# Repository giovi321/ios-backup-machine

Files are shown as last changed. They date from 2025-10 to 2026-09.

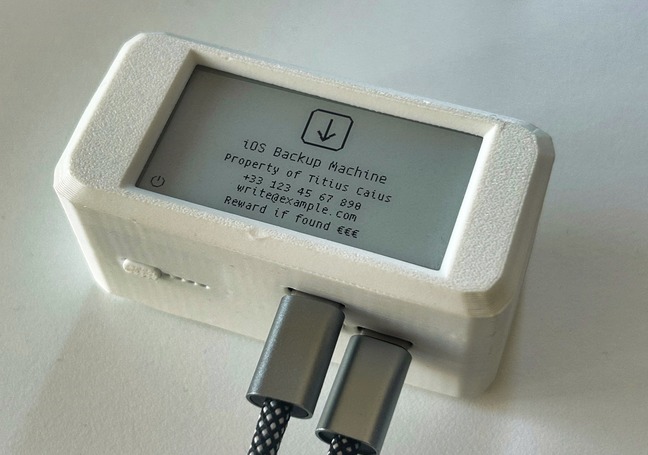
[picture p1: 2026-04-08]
docs/public/assets/images/Image2.jpg

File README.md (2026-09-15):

<p align="center">
  iOS Backup Machine
</p>

<h1 align="center">iOS Backup Machine</h1>

<p align="center">
  
  
  
  
  
</p>

<p align="center">
  
  
  
</p>

<p align="center">
  
</p>

Plug in an iPhone and it backs up on its own. No iCloud, no iTunes, no computer, no account.

The whole appliance runs on a Radxa Zero 3W (an upgraded Raspberry Pi Zero W) with a small e-ink screen and a battery UPS. When you connect a phone, it runs an encrypted `idevicebackup2` backup to the microSD card, shows progress and any errors on the display, and keeps a log you can read later. An optional rsync-over-SSH job ships each backup to a remote server, over WireGuard if you want it off your LAN.

Every backup stays on storage you control, and it can be restored anytime with tools from [libimobiledevice](https://libimobiledevice.org).

Normal operation

> **Personal appliance, not an internet service.** The web UI password is optional and basic, so keep the device on your LAN or reach it over the VPN. The backup payload is encrypted by iOS with a password that never leaves your iPhone.

## Quick start

Flash Armbian on the Radxa Zero 3W, then from the device as root:

```bash
cd /root
git clone https://github.com/giovi321/ios-backup-machine.git
bash ios-backup-machine/install.sh
```

The installer enables the I2C and SPI overlays, installs the packages, builds the Python environment, links the e-Paper driver, installs the systemd services and udev rules, prepares the backup storage, and sets up the PiSugar UPS. When it finishes, open `http://<device-ip>:8080` and complete the first-start wizard.

Full flashing steps, the manual install, and updating are in the [Installation guide](https://giovi321.github.io/ios-backup-machine/getting-started/installation/).

## What it does

- Starts a backup automatically when an iPhone is plugged in, using the iPhone's own encryption
- Shows progress, status, and errors on the e-ink display, with a status icon row for power, VPN, internet, WiFi, and a three-state iPhone icon
- Keeps running on a UPS so a power cut does not corrupt a backup or the filesystem
- Stops a running backup when the backup drive disappears, the drive fills up, or the battery drains, and reports which of the three it was
- Kills a backup that has gone silent, and restarts the daemon if its main loop wedges, so a stuck run does not look like a working one
- Sends one alert when no backup has succeeded for a week, because every other notification only fires when something actually happens
- Ships backups to a remote server over rsync and SSH, with a WireGuard client for off-LAN transfers
- Optionally verifies the sync server's SSH host key against a fingerprint you pin
- Configures everything from a web UI, with a log and journal viewer and a health endpoint for external monitoring
- Encrypts WireGuard, remote sync, and webhook auth credentials at rest with AES-256-GCM

## Documentation

The full documentation is at **[giovi321.github.io/ios-backup-machine](https://giovi321.github.io/ios-backup-machine/)**:

- [Overview](https://giovi321.github.io/ios-backup-machine/getting-started/overview/) and [Hardware](https://giovi321.github.io/ios-backup-machine/getting-started/hardware/)
- [Installation](https://giovi321.github.io/ios-backup-machine/getting-started/installation/) and [First backup](https://giovi321.github.io/ios-backup-machine/getting-started/first-backup/)
- Guides for [backups](https://giovi321.github.io/ios-backup-machine/guide/backups/), [remote sync](https://giovi321.github.io/ios-backup-machine/guide/remote-sync/), [networking](https://giovi321.github.io/ios-backup-machine/guide/networking/), [WireGuard VPN](https://giovi321.github.io/ios-backup-machine/guide/wireguard-vpn/), the [web UI](https://giovi321.github.io/ios-backup-machine/guide/web-ui/), and [logs](https://giovi321.github.io/ios-backup-machine/guide/logs/)
- [Architecture](https://giovi321.github.io/ios-backup-machine/architecture/overview/), including [device connectivity](https://giovi321.github.io/ios-backup-machine/architecture/device-connectivity/) and [security](https://giovi321.github.io/ios-backup-machine/architecture/security/)

## Inspect your backups with Apple Juicer

To browse the backups this device creates, point [Apple Juicer](https://github.com/giovi321/apple-juicer) at the backup directory. It parses artifacts such as WhatsApp and Messages (with Photos, Notes, Calendar, and Contacts in progress), unlocks encrypted backups with the password, and lets you search everything in a browser. Docs: https://giovi321.github.io/apple-juicer/

## Contributing

Issues and pull requests are welcome. See [CONTRIBUTING.md](CONTRIBUTING.md) and the [development docs](https://giovi321.github.io/ios-backup-machine/development/contributing/). Report security issues privately through [Security Advisories](https://github.com/giovi321/ios-backup-machine/security/advisories/new).

## License

MIT License. Includes code adapted from Waveshare's [e-Paper library](https://github.com/waveshareteam/e-Paper).

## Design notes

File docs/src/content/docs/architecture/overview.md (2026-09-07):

---
title: "Architecture overview"
description: One long-running display service owns the e-paper and renders every screen from a single status file, everything else just writes state, and a fault either degrades or restarts the daemon.
---

The design rule is one owner for the e-paper. A single always-on daemon (`iosbackupmachine.service`) holds the display for the whole uptime and draws every screen. Nothing else ever opens the panel. This is what removed the SPI-bus conflicts and the "screen not updating" failures that came from several processes fighting over the same hardware.

Everything else in the system only writes state. The backup logic, remote sync, web UI, and PiSugar button each update a file or drop a small sentinel, and the daemon reads that state and decides what to draw.

System architecture

## The single display owner

The daemon renders all of these from state:

- Boot and idle screen
- Backup progress
- Remote sync progress
- Single-tap system info
- Unplug and interrupted screens
- The power-off owner screen

The rest of the system stays off the panel:

- Backup runs inside the daemon, which detects an iPhone by polling rather than restarting on a udev event. An earlier design restarted the service on plug, which tore down the display owner mid-render.
- Remote sync (`backup-sync.py`) writes progress to the status file, and the daemon draws it.
- The single-tap info screen is handled by the daemon's button listener.
- Unplug is a udev event that only stops a running `idevicebackup2`; the daemon then draws the interrupted screen.
- Shutdown sends the daemon `SIGTERM`, and it paints the owner screen and sleeps the panel so the image survives after power-off.
- The web UI Start and Stop actions drop sentinel files that the daemon consumes, instead of restarting the service.

## State drives the screen

A shared status file is the contract between the writers and the display. The daemon reads it on every tick and paints one full refresh on each screen-type transition, with partial refreshes for animated progress. Because only the daemon touches the panel, there is no lock to contend for and no way for two screens to overlap.

Display state machine

## Failure handling

Because the daemon is the only process that can draw, losing it costs the display for the rest of the uptime. Swallowing every error is the wrong fix, though: a daemon that is alive and doing nothing is the worse failure, since nothing reports it. A fault therefore either degrades to something honest, or exits non-zero so systemd restarts the process.

- Startup faults degrade. An unwritable log directory, a config that crashes the loader, or a panel that will not initialise each cost one capability and leave the rest working, instead of taking the process down.
- Fatal faults exit non-zero, so `Restart=on-failure` on `iosbackupmachine.service` brings a working daemon back rather than leaving a dead one.
- A wedged main loop is caught by a heartbeat watchdog. The loop, and every long hold it can legitimately sit in, beats a timer; if no beat lands inside the window the process logs `[FATAL] main loop stalled` and exits 1.
- Headless is recoverable, not permanent. A daemon running on the no-op panel keeps retrying the real one in the background, so a panel that was busy at boot comes back without a restart. See [Display and controls](../../guide/display-and-controls/#when-the-panel-does-not-come-up).
- A backup is guarded during the run, not only before it. One health probe re-checks the drive, the free space, and the battery every 10 seconds, and a silence timeout and a total cap bound a run that is producing nothing. See [Backups](../../guide/backups/#guards-during-a-backup).
- A `config.yaml` that cannot be read falls back to the built-in defaults instead of failing to start, keeps the bad file for inspection, and says so in the web UI. See [Security](../security/#config-integrity).

Every guard fails open in the direction that keeps the appliance usable: a probe that cannot answer lets the work through, because a guard misfiring on its own broken probe is worse than the failure it was added to prevent. The quiet-device alert is the one inversion, and for the mirror-image reason. It fails silent, because one false alarm there costs the credibility of every later true one.

## Where to go next

- [Device connectivity](../device-connectivity/): how the daemon keeps an iPhone visible and the VPN handshaking
- [Security](../security/): credential encryption, web UI auth, and what the appliance trusts
- [Display and controls](../../guide/display-and-controls/): the screens and the button actions from a user's point of view

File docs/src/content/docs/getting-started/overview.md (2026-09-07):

---
title: "Overview"
description: What the iOS Backup Machine appliance is, its key features, and how a normal backup runs.
---

iOS Backup Machine is an offline, portable, automatic iPhone backup appliance that runs entirely on a Radxa Zero 3W (an upgraded Raspberry Pi Zero W). Plug in an iPhone and the device runs an encrypted `idevicebackup2` backup to local storage, shows progress and messages on a 2.13" e-ink display, and logs all activity locally. No iCloud, no iTunes, you own your data.

Normal operation

## Objective

A self-contained iOS backup appliance with no reliance on Apple services or computers. All backups stay local on the microSD card and can be restored anytime using tools from [libimobiledevice](https://libimobiledevice.org).

## Key features

- Fully automated: starts as soon as an iPhone is plugged in
- Live feedback: the e-ink display shows progress, status, and errors
- Secure: backups use the iPhone's own encryption credentials
- Offline and independent: no Apple ID, no iTunes, no internet required
- Solid: file corruption is prevented by a small UPS
- Guarded runs: a backup is stopped and the reason reported when the backup drive disappears, the drive fills up, the battery drains, or the run hangs
- Quiet-device alert: one notification when no backup has succeeded for a week, since every other notification only fires when something happens
- Web UI: configure all settings from a browser, with a bounded log viewer and a systemd journal viewer for diagnosing a bad run
- Status icons: every e-ink screen shows power, VPN, internet, WiFi, and iPhone indicators at a glance, with a three-state iPhone icon (absent, plugged but untrusted, trusted)
- Multi-network WiFi: configure several networks (each with a nickname); the device roams to whichever is in range, managed through netplan and wpa_supplicant
- NTP sync: auto-syncs the clock when internet is available (WiFi or USB iPhone hotspot)
- Notifications: webhook and MQTT alerts for backup events
- Remote sync: rsync backups to a remote server over SSH (manual or auto after a backup)
- WireGuard VPN: built-in client with encrypted config, auto-connect on boot, WiFi, or iPhone, and an optional full-tunnel mode that keeps local SSH and web UI access
- Credential encryption: WireGuard, remote sync, and webhook auth credentials are encrypted with AES-256-GCM, using either the iPhone UDID (auto-decrypt when connected) or a custom password
- Network-aware sync: restrict remote sync to WiFi only, a specific SSID, or iPhone USB tethering

## How normal operation works

1. Turn on the device: press the PiSugar power button once, then keep it pressed until all LEDs light up
2. Wait for the boot to complete (you will see a screen refresh)
3. Plug in your iPhone and the backup starts automatically
4. Follow the display, which prompts to unlock the phone if needed, shows encryption status, and shows the progress percentage
5. At the end, the display shows a success confirmation and timestamp, plus owner info that persists on screen even after power off or power loss

:::note
If you unplug the iPhone during a backup, the process stops safely and the screen shows the interruption timestamp. Encryption stays active on the iPhone, so the next attempt continues normally.
:::

## Next steps

- [Installation](../installation/)
- [First backup](../first-backup/)
- [Architecture overview](../../architecture/overview/)

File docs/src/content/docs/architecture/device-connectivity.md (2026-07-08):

---
title: "Device connectivity"
description: How the daemon keeps a hot-plugged iPhone visible to usbmux and verifies the VPN actually handshakes.
---

The daemon works around two platform quirks so that plugging in an iPhone "just works" regardless of order or lock state: a usbmux hot-plug gap that hides devices connected after boot, and a VPN that can look up without ever handshaking. Both are handled inside the always-on display daemon, so there is no dependency on udev delivering an event at the right moment.

## The usbmux hot-plug gap

On this Armbian image, `usbmuxd` runs as a persistent service but does not receive libusb hot-plug events. A phone plugged in after boot is enumerated by the kernel (it shows up in `lsusb` as an Apple device, vendor `05ac`) but stays invisible to `idevice_id` and every other `libimobiledevice` tool until `usbmuxd` re-scans. Since the daemon detects an iPhone by polling `idevice_id`, an invisible device blocks backup detection, the trust icon, and the VPN's config decryption at the same time.

The daemon closes the gap itself. On each idle poll, if it finds no device through `idevice_id` but the kernel has enumerated an Apple device in sysfs (`/sys/bus/usb/devices/*/idVendor` reads `05ac`), it restarts `usbmuxd` so the device appears.

The restart is guarded so it never misfires or storms:

- It never runs during a backup, which would drop the `idevicebackup2` usbmux session
- It tracks a sysfs signature of the device (bus path, `devnum`, interface and configuration counts). A fresh plug, or a re-enumeration when you unlock a phone, changes the signature and triggers a restart at once
- A device that stays invisible is retried with exponential backoff (8 seconds up to 120 seconds), so unlocking it later is picked up quickly, and a phone left plugged in and locked does not restart `usbmuxd` on a tight loop

Once `usbmuxd` sees the phone, the backup path and the VPN reconciler both proceed on their next cycle.

:::note[iOS USB Restricted Mode]
A phone that has been locked for about an hour puts its USB data port into Restricted Mode: it charges but exposes no data, so no software on this side can reach it. Unlock the phone once and the daemon picks it up within a few seconds. This is an iOS security feature, not something the appliance can bypass.
:::

## Three trust states

The iPhone status icon reflects what the daemon can actually read, which is what the rest of the system depends on:

- Absent: no iPhone is visible on USB
- Untrusted (closed padlock): the phone is plugged in but lockdown data is not readable yet, either because Trust has not been granted or the phone is locked
- Trusted (checkmark): lockdown data (the serial number) is readable

The trusted state matters beyond the icon. In `udid` decryption mode the WireGuard config is decrypted with the iPhone serial, so the tunnel can only come up once the phone is readable. See [WireGuard VPN](../../guide/wireguard-vpn/) and [Security](../security/).

## Handshake-verified VPN

The VPN reconciler treats a real WireGuard handshake as the definition of "connected", not the mere existence of the `wg0` interface. A tunnel can come up and then never handshake, for example when the endpoint is unreachable or the clock is not yet NTP-synced and the peer rejects the exchange.

The reconciler runs in the display daemon and does two things:

- Brings the tunnel up as soon as a selected auto-connect source appears (iPhone plugged in, WiFi available, or on boot), so it recovers after errors, reconnects, or a hotspot toggled on after the phone was already plugged in, not just on a one-off boot event
- Checks that a handshake completes within a grace window. If the interface is up but no handshake lands, it tears the tunnel down and reconnects

In `udid` mode the reconciler waits for a readable iPhone before it can decrypt the config, and the persisted WireGuard log records `Cannot decrypt: no iPhone connected` while it waits.

For the user-facing view of triggers and the full-tunnel option, see [WireGuard VPN](../../guide/wireguard-vpn/). For the icons, see [Display and controls](../../guide/display-and-controls/).

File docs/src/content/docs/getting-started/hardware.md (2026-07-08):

---
title: "Hardware"
description: The bill of materials and the software stack that make up the iOS Backup Machine appliance.
---

The appliance is built from four hardware parts (a Radxa Zero 3W, a Waveshare e-ink HAT, a PiSugar 3 UPS, and a microSD card) inside a 3D printed case, running an Armbian and Python software stack. This page lists each part and its role.

## Bill of materials

| Component | Purpose | Rationale |
|---|---|---|
| Radxa Zero 3W (8GB eMMC) | Main controller | eMMC is faster and more reliable than a microSD |
| Waveshare 2.13" e-Paper HAT V4 (250x122) | Status display | Persistent output, readable, low power |
| PiSugar 3 | UPS and safe shutdown | Prevents corruption on power loss |
| MicroSD card | Backup storage | Dedicated storage separate from the OS |
| 3D printed case | Enclosure | Based on the design by PiSugar and edited for this purpose |

:::note
The 3D printed case is based on the PiSugar case design, edited to fit this build.
:::

## Software stack

| Component | Role |
|---|---|
| Armbian (Trixie) | Base OS |
| Python 3.13 | Runtime for backup and display scripts |
| libimobiledevice | iPhone communication (`idevicebackup2`, `idevicepair`) |
| udev and systemd | Automation and event handling |
| netplan, systemd-networkd, wpa_supplicant | WiFi management (no NetworkManager) |
| Flask | Web UI for settings |
| WireGuard | Optional VPN client (auto-connect, optional full tunnel) |

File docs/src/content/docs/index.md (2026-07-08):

---
title: "iOS Backup Machine"
description: Offline, automatic iPhone backup appliance on a Radxa Zero 3W, with an e-ink display, a UPS, and encrypted remote sync.
---

<div style="text-align: center; margin-bottom: 1rem;">
  iOS Backup Machine
</div>

Plug in an iPhone and it backs up on its own. No iCloud, no iTunes, no computer, no account. The whole thing runs on a Radxa Zero 3W (an upgraded Raspberry Pi Zero W) with a small e-ink screen and a battery UPS, and every backup stays on local storage you control.

When you connect a phone, the device runs an encrypted `idevicebackup2` backup to the microSD card, shows progress and any errors on the e-ink display, and writes a log you can read later. An optional rsync-over-SSH job ships each backup to a remote server, over WireGuard if you want it off your LAN.

Normal operation

:::caution[Built for a trusted network]
This is a personal appliance, not a hardened internet service. The web UI password is optional and basic, so keep the device on your LAN or reach it over the VPN. The backup payload is encrypted by iOS with a password that never leaves your iPhone.
:::

## Start here

- [Overview](getting-started/overview/): what the appliance does and how a backup runs
- [Hardware](getting-started/hardware/): the parts list and the software stack
- [Installation](getting-started/installation/): flash Armbian and run the installer
- [First backup](getting-started/first-backup/): the setup wizard and your first run

## How it fits together

One long-running display service owns the e-paper and draws every screen from a single status file. Everything else (the backup, remote sync, web UI, and the PiSugar button) only writes state. Backups land on the microSD card, and an optional rsync-over-SSH job copies them to a remote server.

System architecture

Read [Architecture overview](architecture/overview/) for why a single owner removes the SPI-bus conflicts that used to freeze the display.

## Inspect your backups with Apple Juicer

To browse the backups this device creates, point [Apple Juicer](https://github.com/giovi321/apple-juicer) at the backup directory. It parses artifacts such as WhatsApp and Messages (with Photos, Notes, Calendar, and Contacts in progress) and lets you search them in a browser, including unlocking encrypted backups with the password.

- Repository: https://github.com/giovi321/apple-juicer
- Documentation: https://giovi321.github.io/apple-juicer/

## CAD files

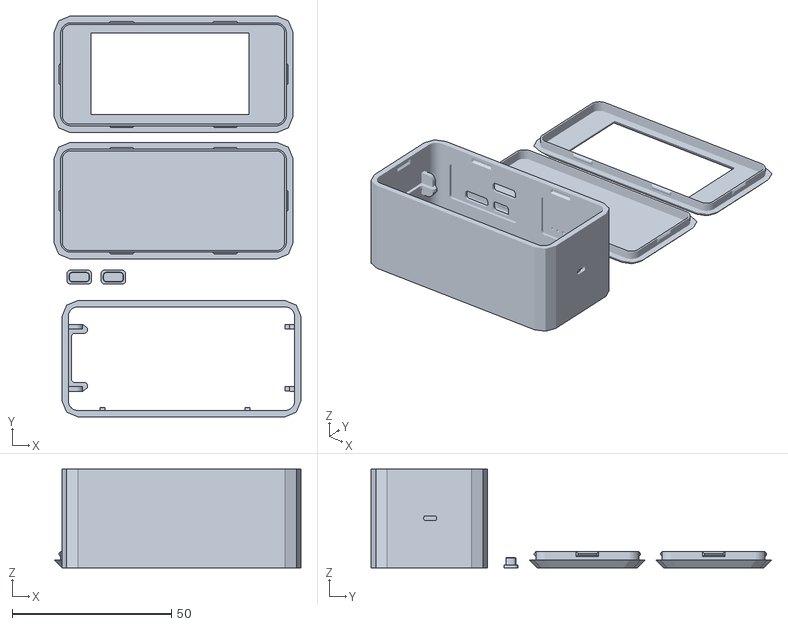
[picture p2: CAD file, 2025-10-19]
assets/case/Case ios backup machine_v8.stl
77.5 x 125.7 x 31.0

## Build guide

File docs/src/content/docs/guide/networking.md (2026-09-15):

---
title: "Networking"
description: How the appliance manages WiFi, roams between saved networks, prefers the iPhone hotspot, and keeps its clock in sync.
---

This page covers how the iOS Backup Machine connects to a network. WiFi is handled by the OS stack (netplan, systemd-networkd, wpa_supplicant), the device roams between the networks you save, and it prefers the iPhone USB hotspot while the phone is plugged in. Network access is optional: backups run fully offline, but a connection enables NTP sync, notifications, remote sync, and remote access.

## WiFi stack

WiFi is managed through the OS's existing netplan, systemd-networkd, and wpa_supplicant stack. The device has no NetworkManager. The `iw` and `wireless-tools` packages read the connected SSID, and `iptables` is used by the WireGuard full-tunnel routing exception.

When you save networks in the web UI, the appliance writes a managed netplan drop-in at `/etc/netplan/90-iosbackup-wifi.yaml` and applies it. The OS's own netplan files are left untouched.

:::note
Only the `90-iosbackup-wifi.yaml` drop-in is owned by the appliance. Your base OS network configuration is never rewritten.
:::

## Multiple networks and roaming

You can configure several networks, each with an optional nickname. wpa_supplicant associates to whichever configured network is in range, so the device roams automatically as you move between them.

Networks are stored in `config.yaml` under `wifi.networks`:

```yaml
wifi:
  enabled: false
  ssid: ""
  password: ""
  networks:
    - nickname: "Home"
      ssid: "HomeNetwork"
      password: "secret"
    - nickname: "Office"
      ssid: "CorpWiFi"
      password: "another-secret"
```

The legacy single `ssid` and `password` fields are the older single-network form. They are migrated into `networks[0]` automatically and kept mirrored for back-compat, so an existing single-network config keeps working.

## iPhone-hotspot preference

The WiFi route is given a higher metric than the iPhone USB tether's route. As a result, the iPhone hotspot is used when the phone is plugged in, and WiFi takes over automatically when the phone is unplugged. The WiFi connection is no longer dropped as the iPhone connects or disconnects.

This handover changes which addresses the device answers on, which matters if you have restricted `webui.bind_interfaces` to specific interfaces rather than `all`. The web UI re-checks the selection every 20 seconds and binds and unbinds as addresses appear and disappear, so a handover mid-sync does not strand it. See [Web UI](../web-ui/#access).

## Scan and connect

The WiFi settings page has a Scan & connect button. It forces a rescan and connects to any saved network in range. Use it when the device is not associated to a network you expect to be reachable.

## Status sources

The connected SSID and its nickname are shown in three places: the dashboard, the e-ink info screen (single-tap system info), and `GET /api/status`. These values are read via `iw`, `iwgetid`, and `wpa_cli`.

The `/api/health` and `/api/status` responses expose the active interface and WiFi details, for example:

```json
"network": {
  "active_ip": "192.168.1.50",
  "interface": "wifi",
  "wifi_ssid": "HomeNetwork",
  "wifi_nickname": "Home",
  "internet": true
}
```

## NTP time sync

When `ntp.enabled` is true, the appliance auto-syncs its clock whenever internet is available, over either WiFi or the USB iPhone hotspot. A correct clock matters beyond timestamps: the WireGuard peer rejects handshakes when the clock is not yet NTP-synced.

```yaml
ntp:
  enabled: true
  servers:
    - "pool.ntp.org"
    - "time.google.com"
```

`ntp-sync.service` runs once at boot, which can easily land before any network is up. `ntp-sync.timer` covers that: it first fires two minutes into the boot and then retries every 15 minutes. The retry is cheap in the steady state, because `ntp-sync.py` exits early once `timedatectl` reports `NTPSynchronized=yes`. The installer both enables and starts the timer, so a fresh or changed timer does not wait for the next boot to begin running.

The clock also gates the quiet-device alert. A board with a dead RTC cell and no network boots reading 1970, so the alert refuses to write its first record until the clock reads at least 2026, and it ignores the first 15 minutes of a boot entirely. Anchoring the record to a 1970 clock would make the next check compute an age of decades and alert on a healthy device.

## Related

- [WireGuard VPN](../wireguard-vpn/) covers the VPN client and its WiFi and boot auto-connect triggers
- [Remote sync](../remote-sync/) covers restricting rsync to WiFi only, a specific SSID, or iPhone USB tethering

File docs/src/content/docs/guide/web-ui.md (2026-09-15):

---
title: "Web UI"
description: The browser interface at port 8080, its first-start wizard, live dashboard, settings pages, authentication, and the login-exempt health endpoint.
---

The web UI is where you configure the appliance and watch it work. Open it at `http://<device-ip>:8080`. On the very first boot it runs a nine-step setup wizard, then it settles into a dashboard with three live cards and a set of settings pages. A login-exempt `GET /api/health` endpoint exposes a JSON snapshot for external monitoring.

## Access

Access the web interface at `http://<device-ip>:8080`. The port is configurable in `config.yaml` under `webui.port`, and `webui.bind_interfaces` selects which network interfaces the UI listens on (options: `all`, `wifi`, `usb_iphone`, `wireguard`). Select several and the UI listens on each one that has an address. The selection is re-checked every 20 seconds, so an interface that comes up later, a WireGuard tunnel or the iPhone hotspot, starts being served without a restart, and one that goes away stops being served. If none of the selected interfaces has an address the UI listens on nothing and records that in the journal, rather than falling back to every interface.

## First-start wizard

On the very first boot, when owner info has not been configured, the web UI shows a guided setup wizard. It opens with an unnumbered step asking you to plug the iPhone in and pair it, then nine numbered ones:

1. Owner information, displayed on the e-ink screen when idle
2. WiFi (optional), for NTP sync, notifications, and remote access
3. Date & time, set manually or with automatic NTP synchronization
4. Backup directory, where backups are stored
5. Backup encryption, set directly on the iPhone (the password is never stored on this device)
6. Device filter (optional), restrict which iPhones can trigger a backup, auto-detects the connected device
7. Notifications (optional), webhook and MQTT alerts for backup events
8. Display orientation, landscape left or right
9. Web UI password (optional), protect the settings interface

The Flask session `secret_key` is generated automatically on first start and saved to `config.yaml`. No manual configuration is needed.

## Dashboard

The dashboard shows three live status cards, each refreshing every 5 seconds, above static System, Storage, and Quick Actions cards and the Reboot / Shut Down buttons:

- Network, showing whether the internet is reachable, which link is carrying it (WiFi with its nickname, or the iPhone's USB hotspot), whether WireGuard is up, and how long the current state has held. The appliance switches links on its own, so how long the current one has lasted sits next to whether it is up. The probe runs on its own schedule and the page reads a cached answer, so polling costs nothing no matter how many tabs are open
- Backup Status, with inline Start Backup and Stop Backup buttons. It shows percentage and encryption status while a backup is running, and stays idle while a remote sync is in progress
- Remote Sync Status, with inline Sync Now (or Cancel Sync, when active) and a Configure shortcut when sync is disabled. It shows percent, transferred and total size, current speed, an ETA, and stall or scanning hints

See [Backups](../backups/) and [Remote sync](../remote-sync/) for what these cards drive.

## Reboot, shutdown, and update while work is running

Reboot, shutdown, and a system update are the three actions that end work in flight. The first two cut the power out from under `idevicebackup2`. The updater stops every service, and the display daemon's `KillMode=mixed` reaps the `idevicebackup2` child along with it. A backup killed that way leaves a half-copied snapshot the next run has to redo, and no `[INTERRUPT]` line in the run log to say why.

All three refuse once while a backup or a sync is running, and offer a button to do it anyway. Taking the override stops the work the sanctioned way first: it drops the stop sentinel the daemon watches and waits up to 10 seconds for `idevicebackup2` to exit, so the run log records why it ended, then it continues.

The refusal is never a hard block. The offer rides on the `?confirm=` query argument of the page you land on, so it disappears as soon as you navigate anywhere else and there is no server-side state to expire or leak between browsers. The busy check itself fails open, because a wedged `pgrep` must not be able to lock you out of powering the device off.

## Pages

The sidebar groups the pages under Backup, Settings, and Tools.

Backup:

- Backup Settings: auto-start toggle, notification on rejected devices. The backup guards and timeouts are config-file only; see [Backups](../backups/#where-these-settings-live)
- Backup List: one row per backup folder on the drive, with the device name, its iOS version, the last backup time, the size (measured in the background), whether the backup completed, and its remote-sync state
- Device Filter: allow only specific iPhones by UDID (auto-detect connected device or manual entry)
- Encryption: enable or change backup encryption on the connected iPhone (password never stored)

Settings:

- General: backup directory, display orientation, owner information, and config export and import
- Date & Time: manual date setting, NTP sync configuration
- WiFi: enable or disable and configure one or more networks, each with an optional nickname, plus a Scan & connect button
- Notifications: webhook URLs and MQTT broker settings (separate test buttons for webhook, MQTT, and both)
- Remote Sync: enable, configure SSH credentials (encrypted), test connection, trigger sync, set network restrictions, and the overall time limit
- WireGuard: upload and encrypt VPN config, start or stop the interface, auto-connect triggers, and a full-tunnel toggle
- Web UI: select which network interfaces the web UI listens on, one or several
- Password: protect the web UI with a password (set, change, or remove)

Tools:

- Logs: browse the log files, with separate live-tail links for the most recent backup and sync log, and a viewer for the systemd journal. See [Logs](../logs/)
- Update: check for a new release and install it, with the output following in `iosbackup-update`. See [Installation](../../getting-started/installation/#updating)

## Authentication

By default the web UI has no password. You can set one during the first-start wizard or later on the Password page. Once set, all pages require login. The password is hashed (SHA-256 plus salt) and stored in `config.yaml`. You can change or remove it at any time.

```yaml
auth:
  password_hash: ""   # auto-managed; set via web UI
```

## Config export and import

The General page exports `config.yaml` as a download and imports one back. An import is migrated and default-filled before it is saved, so a file exported from an older release comes back on the current schema.

The import also reports what it had to correct. A wrong-typed value is silently swapped for its default during the merge, and the corrected tree is what gets saved, so without the report you would never learn which of your settings the import dropped. The first 10 corrections appear as banners and the full list goes to `webui.log`.

Uploads are capped at 256 KB. This import is the only upload in the UI and an exported config is a few KB, so the cap is there for the case where the wrong file gets picked in the browser. Without it, a photo or a backup archive would be read whole into RAM and handed to the YAML parser on a board with 512 MB of it.

## When config.yaml is unreadable

A `config.yaml` that cannot be parsed, or that parses to something other than a settings mapping, does not stop the appliance. The loader falls back to the built-in defaults, keeps the original next to it as `config.yaml.bad-<timestamp>`, and the web UI shows a banner saying so, with the specific problems under Details. The saved settings are gone in that case, including the flag that records setup as finished and the password hash, so the first-start wizard re-engages as the recovery path rather than leaving an open UI that pretends setup was done.

A single mistyped key is handled more narrowly: that value is replaced with its default, a warning is recorded, and the rest of the file is kept.

## Health endpoint

`GET /api/health` returns a JSON snapshot for external monitoring such as Uptime Kuma, Home Assistant, or a cron check. It is login-exempt and contains no secrets: no owner info, credentials, or keys.

```json
{
  "status": "ok",
  "warnings": [],
  "version": "4.10.0",
  "time": "2026-05-30T11:13:31",
  "services": { "iosbackupmachine": "active", "webui": "active",
                "pisugar-server": "active", "usbmuxd": "active" },
  "disk":     { "root": {}, "backup": { "free": "...", "percent": 42.0 } },
  "battery":  { "percent": 62.0, "charging": false },
  "network":  { "active_ip": "192.168.1.50", "interface": "wifi",
                "wifi_ssid": "HomeNetwork", "wifi_nickname": "Home",
                "internet": true, "wireguard": {} },
  "backup":   { "state": "complete", "last_backup_time": "..." },
  "sync":     { "state": "sync_complete", "timestamp": "..." }
}
```

The `status` field is a rollup, and `warnings` names each condition that contributed:

- `error`: `iosbackupmachine.service` or `webui.service` failed, or the backup disk is at 95 percent or more
- `warning`: battery below `sync.min_battery_percent` while not charging, no internet, the last backup errored, or no backup has succeeded for `backup.stale_after_sec` (reported as `no backup in N days`)
- `ok`: none of the above

The stale warning is the pull half of the quiet-device alert described in [Backups](../backups/#the-quiet-device-alert). A poller reading this endpoint catches both a device that is up but quiet and a device that has stopped answering, and the second of those is something the device can never report about itself.

:::note
`GET /api/health` is the only endpoint exempt from login, so external monitors can poll it even when a web UI password is set.
:::

## Notifications

Backup and sync events can be sent via webhook (JSON POST) and MQTT. Supported events: `backup_start`, `backup_complete`, `backup_error`, `backup_stale`, `sync_start`, `sync_complete`, `sync_error`, `device_connected`, `device_disconnected`, `device_rejected`. Configure them on the Notifications page or directly in `config.yaml`. An empty event list means every event.

A `backup_error` carries its own `reason_code` drawn from the backup guards and timeouts; see [Backups](../backups/#notifications).

### The `sync_error` payload

A failed sync sends the same verdict its log records, structured so an automation can act on it without matching English:

```json
{
  "event": "sync_error",
  "timestamp": "2026-05-14T22:15:14+0200",
  "source": "iosbackupmachine",
  "error": "Sync failed at 40% (20.0 GB of 50.0 GB) after 1h10m: SSH/connection error (host unreachable, auth, or link dropped) [exit 255]",
  "reason_code": "ssh_connection_failed",
  "summary": "SSH/connection error (host unreachable, auth, or link dropped)",
  "exit_code": 255,
  "percent": 40,
  "bytes_transferred": 21474836480,
  "bytes_total": 53687091200,
  "duration_seconds": 4200,
  "last_file": "00008030-.../Snapshot/9c/9c11ab04",
  "diagnostics": [
    "no OOM kill of rsync in recent dmesg",
    "remote 192.168.1.50:22 unreachable ([Errno 110] Connection timed out)",
    "wg0 last handshake 12m ago"
  ]
}
```

`reason_code` is the field to branch on. It is stable: codes are added, never renamed. The current set:

| Group | Codes |
|---|---|
| Never started | `sync_disabled`, `config_incomplete`, `credentials_unavailable`, `host_key_mismatch`, `network_not_allowed`, `battery_low`, `tool_missing` |
| Aborted by a watchdog | `scan_timeout`, `stall_timeout`, `battery_abort`, `run_timeout` |
| rsync exited non-zero | `ssh_connection_failed`, `rsync_protocol_error`, `socket_io_error`, `file_io_error`, `source_selection_error`, `partial_transfer`, `remote_timeout`, `out_of_memory`, `rsync_usage_error`, `killed_by_signal`, `no_exit_status`, `rsync_error` |
| Anything else | `internal_error` |

`error` repeats `message` so an existing consumer reading `error` keeps working. Fields the failure does not know are `null`: a sync that never started reports no percentage rather than a misleading `0`.

### Delivery

Webhook and MQTT deliveries run on background threads so a slow endpoint never holds up a backup or a sync. Short-lived callers wait for them before exiting, via `notifications.flush()`; that call is also registered with `atexit`, so a delivery cannot be cut short by the process ending.

Delivery is best-effort and is not retried. A notification reporting a network failure has to travel over the network that just failed, so a `sync_error` caused by a dead link may not arrive. The sync log on the device is the authoritative record; see [Logs](../logs/).

### Webhook auth and the iPhone

The optional webhook auth header is encrypted with the iPhone's serial number, so decrypting it needs the phone attached. Most events that carry it do not fire while it is: `device_disconnected` by definition, every `sync_*` after the phone was unplugged, and `backup_complete`, which is sent just after the screen has invited you to unplug.

The resolved header is therefore cached in `/run/iosbackupmachine/webhook_auth.json`, owner-only, and reused when the phone is absent. `/run` is a systemd tmpfs: RAM-only, cleared at every boot and never written to the SD card, so a powered-off device still gives nothing away without the phone. Only the derived header is cached, never the passphrase - the passphrase also unlocks the WireGuard and remote-sync credentials.

The cache is refreshed whenever the phone is seen, primed at the start of every backup, and dropped when notification settings are saved. Set `IOSBACKUP_WEBHOOK_AUTH_TTL` to a number of seconds to expire it sooner; the default of `0` means it lasts until the next reboot.

If auth is enabled and no header can be obtained, the webhook is skipped rather than sent unauthenticated, and the reason is written to the run's log.

## Related

- [Backups](../backups/) for the backup flow the dashboard controls
- [Remote sync](../remote-sync/) for the sync card and its network restrictions
- [Security](../../architecture/security/) for password hashing and credential encryption

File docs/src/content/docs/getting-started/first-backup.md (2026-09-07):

---
title: "First backup"
description: Complete the first-start wizard, set backup encryption on the iPhone, run the first backup, and restore when needed.
---

After installation, open the web UI at `http://<device-ip>:8080` and complete the first-start wizard, then set backup encryption on the iPhone and run the first backup. The first backup is a full, slow run; every later backup is incremental and much faster.

## First-start wizard

On the very first boot (when owner info has not been configured), the web UI automatically shows a guided setup wizard. It also re-engages if `config.yaml` ever has to be discarded, since the saved setup state goes with it.

The wizard opens with an unnumbered step: plug the iPhone in over USB, click Pair Device, and tap Trust on the phone. Do that before finishing setup, because two later steps (encryption and the device filter) need a readable phone. Then it walks through nine steps:

1. Owner information, displayed on the e-ink screen when idle
2. WiFi (optional), to connect to a wireless network for NTP sync, notifications, and remote access
3. Date and time, set manually or with automatic NTP synchronization
4. Backup directory, where backups are stored
5. Backup encryption, set directly on your iPhone (the password is never stored on this device)
6. Device filter (optional), to restrict which iPhones can trigger a backup; it auto-detects the connected device
7. Notifications (optional), webhook and MQTT alerts for backup events
8. Display orientation, landscape left or right
9. Web UI password (optional), to protect the settings interface

The Flask session `secret_key` is generated automatically on first start and saved to `config.yaml`, so no manual configuration is needed.

## Backup encryption

Set backup encryption during the wizard, or later from the Encryption page in the sidebar. Enter a password with your iPhone connected and unlocked. The password is sent directly to the iPhone.

:::caution
The encryption password is never stored on this device. Write it down. Without it you cannot restore an encrypted backup.
:::

If no iPhone is connected during setup, skip the encryption step and visit the Encryption page later when your iPhone is plugged in.

## Run the first backup

1. Plug in your iPhone, unlock it, and tap Trust when prompted
2. The first backup runs; this takes a long time depending on device storage
3. All subsequent backups are incremental and much faster

If the first backup is interrupted, encryption (if enabled) remains active on the iPhone. The next backup attempt proceeds normally and no data is lost.

## Restoring a backup

To restore a backup, plug your iOS device into a computer, plug the microSD card into the same computer, and run:

```bash
idevicebackup2 restore --password <your backup password> /media/sdcard/iosbackup/
```

## Related pages

- [Backups](../../guide/backups/)
- [Web UI](../../guide/web-ui/)

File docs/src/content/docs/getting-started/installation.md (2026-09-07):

---
title: "Installation"
description: Flash Armbian, run the automated installer, complete setup in the web UI, and keep the appliance updated.
---

Install the appliance in three moves: flash Armbian on the Radxa Zero 3W, run the automated installer over SSH, then finish setup in the web UI at `http://<device-ip>:8080`. A manual, step-by-step reference is included at the end for anyone who prefers to install by hand.

## Flash Armbian on the Radxa Zero 3W

Follow the [Radxa Zero 3W official guide](https://docs.radxa.com/en/zero/zero3/low-level-dev/install-os-on-emmc). In short:

```bash
apt install rkdeveloptool
rkdeveloptool db rk356x_spl_loader_ddr1056_v1.12.109_no_check_todly.bin
xz -d Armbian_community_25.11.0-trunk.334_Radxa-zero3_trixie_vendor_6.1.115_minimal.img.xz
rkdeveloptool wl 0 Armbian_community_25.11.0-trunk.334_Radxa-zero3_trixie_vendor_6.1.115_minimal.img
rkdeveloptool rd
```

## Automated install (recommended)

After flashing Armbian and logging in as root, clone the repository and run the installer:

```bash
cd /root
git clone https://github.com/giovi321/ios-backup-machine.git
bash ios-backup-machine/install.sh
```

The repository is cloned to `/root/ios-backup-machine/` and the application is installed to `/root/iosbackupmachine/` (a flat directory holding the venv and app files).

### What the installer does

- Enables I2C and SPI overlays in `/boot/armbianEnv.txt`
- Installs system packages (`libimobiledevice`, `python3`, `wireguard-tools`, and others)
- Creates a Python virtual environment and installs dependencies
- Clones and links the Waveshare e-Paper driver
- Copies application files to `/root/iosbackupmachine/`
- Migrates config, merging new defaults without overwriting existing settings, and reports which keys it added
- Installs the systemd units and udev rules, enables the six units the appliance needs, and starts any enabled timer instead of leaving it armed for the next boot
- Prepares the backup storage directory
- Downloads and configures the PiSugar UPS
- Runs a post-install health check
- Prompts to reboot when overlay changes were made or a release sets a reboot flag, so the always-on display daemon reloads

## Complete setup in the web UI

After the script finishes, open the web UI at `http://<device-ip>:8080` to complete the first-start wizard. See [First backup](../first-backup/) for the wizard steps and the first backup run.

## Updating

From the web UI: go to Tools > Update, click "Check for Updates", then "Install Update". The device reboots when the update finishes, so the web UI and the VPN are unreachable for about a minute. The e-ink shows `Updating - device will reboot` for the whole run.

From SSH:

```bash
bash /root/ios-backup-machine/update.sh
```

The update process:

- Stops all services before touching files
- Backs up the current installation, keeping the last 5 backups in `/root/iosbackupmachine-backups/`
- Pulls the latest code from GitHub
- Migrates config, adding new settings without overwriting your values
- Runs the installer with a post-install health check
- Restarts services, then reboots: always for a web UI update, and after a prompt over SSH when the release requires one

An update started from the web UI runs in its own systemd unit (`iosbackup-update`), not as a child of the web UI, so restarting the web UI partway through the install cannot cut it short. Follow it with `journalctl -u iosbackup-update -f`, or read `/var/lib/iosbackupmachine/update.log` afterwards.

<details>
<summary>Manual installation (step-by-step reference)</summary>

If you prefer to install manually, follow these steps after flashing Armbian.

#### Enable I2C and SPI

Edit `/boot/armbianEnv.txt`:

```text
overlays=rk3568-spi3-m1-cs0-spidev rk3568-i2c3-m0
overlay_prefix=rk35xx
```

Reboot.

#### Install dependencies

```bash
apt update
apt install -y python3 python3-venv python3-pil python3-periphery \
  libimobiledevice-1.0-6 libimobiledevice-utils usbmuxd \
  wireguard-tools iptables sshpass rsync netcat-traditional \
  iw wireless-tools git
```

WiFi is managed through the OS's existing netplan, systemd-networkd, and wpa_supplicant stack (the device has no NetworkManager). `iw` and `wireless-tools` read the connected SSID, and `iptables` is used by the WireGuard full-tunnel routing exception.

#### Create the Python virtual environment

```bash
python3 -m venv /root/iosbackupmachine
source /root/iosbackupmachine/bin/activate
pip install -r /root/ios-backup-machine/requirements.txt
deactivate
```

#### Clone repositories and install drivers

```bash
cd /root
git clone https://github.com/waveshareteam/e-Paper.git
git clone https://github.com/giovi321/ios-backup-machine.git
cp ios-backup-machine/app/epdconfig.py e-Paper/RaspberryPi_JetsonNano/python/lib/waveshare_epd/
```

The application files live under `app/`, the systemd units under `services/`, and the udev rules and the PiSugar config under `config/`. The installer flattens `app/` into `/root/iosbackupmachine/`, which is why the modules import each other by bare name.

Link the driver into the venv (adjust the Python version if needed):

```bash
ln -s /root/e-Paper/RaspberryPi_JetsonNano/python/lib/waveshare_epd   /root/iosbackupmachine/lib/python3.13/site-packages/
```

#### Install systemd and udev integrations

```bash
cp ios-backup-machine/config/*.rules /etc/udev/rules.d/
cp ios-backup-machine/services/*.service ios-backup-machine/services/*.timer /etc/systemd/system/
systemctl daemon-reload
systemctl enable iosbackupmachine.service webui.service ntp-sync.service \
  rtc-sync.service wg-autoconnect.service
systemctl enable --now ntp-sync.timer
udevadm control --reload-rules
udevadm trigger
```

`iosbackupmachine.service` is the always-on display daemon. Those five units plus the timer are exactly what the installer enables. The rest of `services/` (`backup-sync.service`, `unplug-notify.service`, `usbmux-refresh.service`) are one-shots started on demand by udev or the PiSugar button, so they are installed but deliberately not enabled. A sync started from the web UI runs in its own transient `iosbackup-web-sync` unit rather than through `backup-sync.service`.

`ntp-sync.timer` needs `--now`. Enabling a timer only arms it for the next boot, and the whole point of this one is to retry a clock sync that failed while the network was still coming up.

#### Prepare backup storage

```bash
mkdir -p /media/iosbackup
touch /media/iosbackup/.foldermarker
```

#### Configure the PiSugar UPS

Install from the official script and add the project config file:

```bash
wget https://cdn.pisugar.com/release/pisugar-power-manager.sh
bash pisugar-power-manager.sh -c release
rm /etc/pisugar-server/config.json
cp "/root/ios-backup-machine/config/[pisugar]config.json" /etc/pisugar-server/config.json
```

Quote that path. Unquoted, `[pisugar]` is a shell character class and the copy silently matches nothing. The file sets the three button gestures, the 30% `auto_shutdown_level`, and the soft power-off shell that lets the display daemon paint the owner screen before the board goes down.

Set the RTC time from the current time of the Radxa Zero:

```bash
apt install netcat-traditional
echo "rtc_pi2rtc" | nc -q 1 127.0.0.1 8423
```

Set the Radxa Zero time from the RTC at every boot:

```bash
systemctl enable rtc-sync.service
```

</details>

## Next step

Continue to [First backup](../first-backup/) to complete the first-start wizard and run your first backup.

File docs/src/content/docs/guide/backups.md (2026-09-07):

---
title: "Backups"
description: How automatic backups start, the auto-start and device-filter controls, encryption, the guards that stop a bad run, and backup notifications.
---

Plug in your iPhone and the backup starts automatically. This page covers the auto-start toggle, the device filter that restricts which iPhones can trigger a backup, how encryption is set, the guards that refuse or stop a run that cannot finish safely, the alert for a device that has quietly stopped backing up, and the notification events fired around a backup.

## Automatic start

When an iPhone is plugged in, the system runs an encrypted `idevicebackup2` backup to local storage. The display prompts you to unlock the phone if needed, shows encryption status, and shows progress percentage, then confirms success with a timestamp. The first backup takes a long time depending on device storage; later backups are incremental and much faster.

### Auto-start toggle

Auto-start is on by default (`backup.auto_start: true`). It controls whether plugging in an iPhone starts a backup on its own. With it off, plugging in a phone does not start a backup, but you can still start one manually with the web UI Start Backup button or a double-tap of the PiSugar button (see [Display and controls](../display-and-controls/)).

You can toggle it under Backup Settings in the [Web UI](../web-ui/).

## Device filter

The device filter restricts which iPhones can trigger a backup:

- Enable the filter in Device Filter settings
- Add devices by connecting an iPhone and clicking "Add connected device", or enter a UDID manually
- When a non-allowed device is plugged in, the backup is blocked and a notification is sent (configurable via `backup.notify_on_rejected`)

When the filter is disabled (the default), any iPhone triggers a backup.

## Backup encryption

Backups use the iPhone's own encryption credentials. You set the password during the first-start wizard, or later from the Encryption page, with your iPhone connected and unlocked. The password is sent directly to the iPhone and is never stored on this device.

:::caution
Because the password is never stored on the device, write it down. You need it to restore a backup. If no iPhone is connected during setup, skip the encryption step and return to the Encryption page later when the phone is plugged in.
:::

If a first backup is interrupted, encryption (if enabled) stays active on the iPhone, and the next attempt proceeds normally with no data lost.

For how credentials and encryption fit the wider threat model, see [Security](../../architecture/security/).

## Power loss

The PiSugar 3 UPS keeps the board running through a mains cut, so losing power does not corrupt a backup or the filesystem. A soft power-off from the PiSugar button runs `shutdown.sh`, which stops the display daemon first so it can paint the owner screen and sleep the panel, and only then shuts the system down.

At 30% battery PiSugar cuts power to the board on its own (`auto_shutdown_level` in its own config). That one is not a graceful shutdown, which is why the battery guards below refuse or stop a backup before it gets there.

## Guards before a backup starts

Three checks run before `idevicebackup2` is launched. Any one of them refuses the run, puts the reason on the display, and sends a `backup_error` notification, since nothing else reports a refusal to anyone who is not standing in front of the panel.

- Backup drive: the marker file (`marker_file`, `.foldermarker` by default) must exist inside `backup_dir`, and a probe write must succeed. A drive that came back read-only fails here instead of crashing `idevicebackup2` part-way through
- Free space: at least 200 MB on the root filesystem, and at least 500 MB on the backup drive, or `backup.min_free_mb` when that is higher (512 MB with the shipped default)
- Battery: at least `backup.min_battery_percent` (default 35) unless the device is charging

The battery floor sits above PiSugar's own 30% auto-shutdown, which is the point of the number. A backup started at 33% is a backup cut mid-write, with nothing in any log to say why and a half-written folder on the drive. The check fails open in every direction the probe itself can fail: an unreadable UPS, no power module at all, or a floor of `0` all let the run proceed.

## Guards during a backup

Each of those conditions can stop being true while a run is going. One health probe re-checks them every 10 seconds, on the thread already reading `idevicebackup2`'s output, and stops the run when one trips.

| Reason code | What tripped |
|---|---|
| `mount_lost` | The backup drive disappeared: the marker file vanished, or the mountpoint's device id changed |
| `disk_full` | Free space on the backup drive fell below `backup.min_free_mb`, or the root filesystem fell below 200 MB |
| `battery_abort` | The battery read below `backup.min_battery_percent` on two checks a minute apart, while not charging |

The reason code appears on the display, in the run log as an `[INTERRUPT]` line, and as `reason_code` in the `backup_error` notification.

`mount_lost` is the one abort with no grace period: `idevicebackup2` is killed outright, because every further second is written into the now-empty mountpoint on the root filesystem. The other two send `SIGTERM` first, so the file in flight is finished and the partial backup stays resumable.

The mount check waits for two consecutive misses of the marker file before it fires, because a single I/O error on a drive under load reads exactly like an unmounted drive, and killing a 40 GB run over one is worse. A changed device id fires at once: that is positive evidence the drive is gone, not an absence of evidence.

## Hang and runaway timeouts

Two limits bound a run that is producing no outcome at all:

- `backup.hang_timeout_sec` (default 600): `idevicebackup2` silent for this long counts as hung and is terminated, reported as `silent`
- `backup.max_duration_sec` (default 14400, four hours): the total cap for one run, reported as `overtime`

Separately, the daemon's main loop feeds a heartbeat watchdog. If no beat lands in time, the process logs `[FATAL] main loop stalled` and exits non-zero, and `Restart=on-failure` on `iosbackupmachine.service` brings back a working daemon.

## The quiet-device alert

Every other notification is edge-triggered: something happened, so something is sent. Nothing reports the absence of events, so a device that quietly stops backing up would tell nobody until a restore is needed. The phone stops being plugged in, auto-start gets switched off, the device filter starts rejecting, and the appliance sits there looking healthy.

`backup_stale` covers that case. When no backup has succeeded for `backup.stale_after_sec` (default 604800, seven days), one notification goes out. One per quiet stretch, not one per check: the alert is keyed to the timestamp it is reporting on, so a reboot, a restart, or a system update cannot re-fire an alert that already went out, and the next successful backup moves the key forward and re-arms it. There is no repeat interval and no snooze to get wrong.

Set `backup.notify_stale: false` to switch it off, or `backup.stale_after_sec: 0`.

The same verdict shows up in two more places. The e-ink info screen appends `(stale)` to its `Backup:` line, and `GET /api/health` reports a `no backup in N days` warning. The health endpoint matters here because a poller also notices the device being unreachable, which a push notification from the device itself can never report.

:::note
The first time this version runs on a device that already has backups, the record is seeded from the newest backup folder rather than reporting "never backed up". That delays a first alert by at most one threshold and corrects itself at the next completed backup.
:::

## Where these settings live

Auto-start and the rejected-device notification are the only two with web UI controls, on the Backup Settings page. Everything else on this page is edited in `config.yaml` under `backup:`.

The timeouts and the two guard floors are read when the display daemon starts, so restart `iosbackupmachine.service` after changing them. `notify_stale` and `stale_after_sec` are re-read on every check and take effect without a restart.

## Notifications

Backup-related events can be sent by webhook (JSON POST) and/or MQTT:

- `backup_start`
- `backup_complete`
- `backup_error`
- `backup_stale` (see [The quiet-device alert](#the-quiet-device-alert) above)
- `device_connected`
- `device_disconnected`
- `device_rejected`

Configure targets and which events to send in the web UI or directly in `config.yaml`. Remote sync fires `sync_start`, `sync_complete`, and `sync_error` through the same two channels and the same event list; see [Web UI](../web-ui/#notifications).

A `backup_error` carries a `reason_code` naming what stopped the run: `mount_lost` or `disk_full` from either the pre-backup gate or the in-run probe, `battery_low` when the pre-backup gate refused on battery, `battery_abort` when the in-run probe stopped a running backup on battery, and `silent` or `overtime` from the timeouts above. An `idevicebackup2` failure carries the numeric `code` from `error_codes` instead.

A `backup_complete` that ends a quiet stretch carries `was_stale: true` and `stale_days`, so an automation can report the recovery from an event it already subscribes to.

## Related

- [First backup](../../getting-started/first-backup/) for the initial setup walkthrough
- [Web UI](../web-ui/) for the settings pages
- [Security](../../architecture/security/) for encryption and credential handling

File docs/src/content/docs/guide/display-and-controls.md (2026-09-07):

---
title: "Display and controls"
description: The e-ink screens the daemon renders, the status icon row, the PiSugar button gestures, and what happens when the panel will not come up.
---

The 2.13" e-ink display (Waveshare 2.13" e-Paper HAT V4, 250x122) is driven by a single always-on daemon that renders every screen from a shared status file, and the PiSugar button gives you three actions without a browser: system info, start a backup, and start a remote sync. This page lists the screens, the status icons in the bottom-left of every live screen, what each button gesture does, and how the daemon carries on when the panel is unavailable.

## Who owns the display

The always-on `iosbackupmachine.service` daemon is the only process that opens the e-paper panel. It holds the panel for the whole uptime and draws every screen from state. Everything else (backup, remote sync, web UI, PiSugar button) only writes state and never touches the display. Each screen-type transition does one full refresh; animated progress uses partial refresh.

:::note
Because one process owns the panel, screens never fight over the SPI bus. The daemon samples icon state in the background, so the status row never blocks or overlaps the screen text.
:::

## When the panel does not come up

A display that will not initialise does not take the daemon down with it. The daemon logs the failure, switches to a no-op panel, and keeps doing everything else: backups still run, the web UI still works, notifications still go out.

Headless is not a final state. The daemon retries the panel in the background, first 30 seconds after it dropped out and then doubling up to a 15 minute gap. A panel that only needed a moment recovers within about half a minute: `spidev` or `gpiochip` not enumerated yet at boot, the previous instance still holding the GPIO lines through its 20 second stop timeout, or BUSY stuck from an interrupted refresh. A unit built with no panel at all pays one failed SPI open every 15 minutes, and repeated failures are logged only when the reason changes, so that unit prints one line for the whole run.

A panel that initialised and then starts failing draws is handled from the other end: after 30 consecutive draw failures the daemon re-initialises it once, since a stale SPI or GPIO handle can recover, and falls back to headless only if that also fails.

## Screens

The daemon renders these screens from state:

- Boot / idle: on boot it shows the project icon, the "iOS Backup Machine" title, and owner info. When idle it shows the last backup result, timestamp, disk usage, and owner info
- Backup progress: prompts to unlock the phone if needed, shows encryption status and progress percentage, then a success confirmation with timestamp at the end
- Sync progress: transferred / total size, current speed, and a progress bar (see [Remote sync](../remote-sync/))
- System info: shown for 30 seconds after a single button tap (see below), then returns to whatever was on screen before the tap. Its `Backup:` line gains a `(stale)` suffix when no backup has succeeded for `backup.stale_after_sec`, since this is the screen someone taps when they wonder whether the thing is still working
- Unplug / interrupted: if you unplug the iPhone mid-backup the process stops safely and the screen shows the interruption timestamp
- Backup stopped by a guard: the backup drive disappearing, the drive filling up, or the battery draining stops the run and names the reason on the normal error screen. The interrupted screen has room for a header and a timestamp and nothing else, so the aborts that have something specific to say use the error screen instead. See [Backups](../backups/#guards-during-a-backup)
- Updating: shown for the whole of an update started from the web UI, and painted again as the daemon's last frame before the installer stops it. E-paper holds the image with the daemon down and through the reboot that ends the update
- Power-off owner screen: owner info only. The daemon paints it on shutdown and sleeps the panel, so the image persists on e-paper after power-off or power loss

Errors appear directly on the display.

## Status icons

Every live screen (boot/idle, backup, sync, info, interrupted, complete) draws a row of status icons in the bottom-left corner. From the set: power (always on), VPN, internet, WiFi, and iPhone. The VPN, internet, and WiFi icons are crossed out with a "/" when that connection is inactive.

The power-off owner screen and the updating screen omit the icon row - during an update the icons would freeze mid-run and read as live.

### The three-state iPhone icon

The iPhone icon has three states, so the trust state (which udid-mode decryption depends on) is visible at a glance:

- Crossed out: no iPhone seen on USB
- Closed padlock: iPhone plugged in but not readable yet, because Trust has not been granted or the phone is locked
- Checkmark: iPhone plugged in and trusted, lockdown is readable, so the WireGuard config can be decrypted

## PiSugar button controls

The daemon's button listener handles the PiSugar power button. Three gestures:

- Single tap: shows the system-info screen for 30 seconds, then returns to whatever was on screen before. It works whatever the device is doing, including mid-backup and mid-sync. It lists date/time, active network (WiFi / iPhone hotspot / Ethernet), IP, VPN state, last backup, last sync, SoC temperature, and disk free %
- Double tap: starts an iPhone backup, the same action as the web UI Start Backup. It needs an allowed iPhone connected and works even when auto-start is off (see [Backups](../backups/))
- Long press: triggers a remote sync to the configured server over rsync-over-SSH. The display then shows transferred / total size, current speed, and a progress bar (see [Remote sync](../remote-sync/))

:::tip
The double-tap backup and long-press sync work without opening the web UI, so the device is fully usable headless.
:::

For how the single-owner display model fits the rest of the system, see the [Architecture overview](../../architecture/overview/).

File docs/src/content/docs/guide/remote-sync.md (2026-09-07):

---
title: "Remote sync"
description: Copy backups to a remote server over rsync-over-SSH, with progress, stall detection, and power-aware, resumable transfers.
---

Remote sync ships your backups to a remote server over rsync-over-SSH, run manually or automatically after each backup. This page covers authentication, how a sync is triggered, the network and battery conditions that gate it, the progress and error reporting on both the e-ink and the dashboard, and how a transfer resumes after a reboot.

The receiving server needs `rsync` installed.

:::note
Install rsync on the remote with `sudo apt install rsync`. Without it the sync cannot complete.
:::

## Transport and authentication

Sync uses rsync over SSH and supports both SSH key and password authentication. Configure the server and credentials in the web UI under Remote Sync; credentials are stored encrypted.

## Host key verification

By default the device trusts the first host key it sees (`StrictHostKeyChecking=accept-new`), which
protects later syncs but not the first one. Tick **Verify the server's SSH host key** on the Remote
Sync settings page to pin the server's key instead: the sync then refuses to run unless the server
presents exactly the key you configured.

Get the fingerprint from the server itself:

```sh
ssh-keygen -lf /etc/ssh/ssh_host_ed25519_key.pub
```

Paste the `SHA256:...` value into **Host Key Fingerprint**. **Fetch from server** fills it in for you,
but it reads the key over the same network you are trying to protect, so treat it as a convenience and
confirm the value out-of-band before saving.

Verification runs before any data is transferred, on both Test Connection and every sync. A mismatch
fails the sync with `Host key mismatch - refusing to connect`, naming the expected and offered
fingerprints. If you legitimately rebuilt the server or rotated its host key, update the stored
fingerprint; until then, syncs stay blocked.

Untick the checkbox to go back to accept-new.

## Triggering a sync

- Manual: long-press the PiSugar button, or click Sync Now on the web UI dashboard or the Remote Sync settings page
- Auto-sync: optionally trigger a sync after each successful backup

## Network restrictions

You can limit when a sync is allowed to run, with `sync.allowed_network`:

- `any`: no restriction, and the default
- `wifi`: only while a WiFi address is up
- `wifi_ssid`: only on the SSID named in `sync.allowed_ssid`. Picking Specific WiFi SSID in the web UI reveals the field that writes it, and leaving the field empty falls back to "any WiFi"
- `usb`: only while the iPhone USB tether is up

A refused sync reports `network_not_allowed` and names the restriction it hit. The check fails open if `netutil` cannot be imported.

## Connection errors

Before transferring, a pre-flight check reports the actual cause of a failure on both the e-ink and the dashboard, instead of a raw rsync exit code. The messages:

- No network connection
- VPN not connected
- No internet connection
- Sync server unreachable

If your sync depends on the tunnel, see [WireGuard VPN](../wireguard-vpn/); for the network options, see [Networking](../networking/).

## Progress display

The e-paper screen and the web dashboard show transferred / total size, current speed, percentage, and a progress bar. Sizes auto-scale across KB, MB, GB, and TB.

During the initial file-list scan (rsync `--no-inc-recursive`) you see "Building file list (Xs)" instead of fake progress, because rsync has not yet computed the total. The total size is measured by walking the backup directory while that scan runs, so it is a real figure rather than one inferred from rsync's rounded percentage, and it does not drift during the transfer.

## Stall detection

Once the transfer is running, rsync going quiet for 5 minutes puts a yellow "Stalled" badge on the dashboard and switches the e-ink to "Sync STALLED". After 30 minutes without output the sync is auto-aborted with a `sync_error` reading "Sync stalled 30 min, aborted.". The thresholds are deliberately generous: on a backup of many small files over SSH, rsync can legitimately go quiet for minutes at a time between bursts.

The file-list scan has its own limit, because it produces no progress output at all: if rsync writes nothing for 30 minutes during that phase, the sync is aborted with "No progress 30 min, aborted.".

## Overall time limit

Off by default. Remote Sync settings has a **Time limit** field in minutes; leave it empty for no limit.

There is deliberately no default. The stall watchdogs above already abort a sync that has stopped moving, so a limit here only bounds a transfer that is still working - and a first sync of a large backup set legitimately runs for many hours. A limit that fires mid-transfer reports `run_timeout` and reads like a failure, even though nothing failed. The partial transfer resumes on the next run either way, because `--partial-dir` is always in use.

## Cancelling

While a sync is in progress, a Cancel Sync button appears on the dashboard and the Remote Sync settings page. It kills `rsync` and `backup-sync.py` immediately and reports "Cancelled by user.". The end state (complete, failed, or cancelled) stays on the e-ink until another event, such as a new sync, a backup start, or a service restart.

## Keepalive

SSH keepalive is set to `ServerAliveInterval=30` with `CountMax=3`, so a dead TCP connection is detected in about 90 seconds.

## Resumable across reboots

rsync runs with `--partial --partial-dir=.rsync-partial`, so a reboot or power loss mid-sync resumes from where it stopped instead of restarting from zero. Incomplete files live in `.rsync-partial/` on the remote.

## Power-aware behavior

A sync will not start, and an in-progress sync auto-aborts, when the battery is below `sync.min_battery_percent` (default 35%) and the device is not charging. This keeps a long transfer from being cut mid-way by PiSugar's 30% auto-shutdown. The aborted transfer resumes on the next run.

:::tip
The threshold is tunable in `config.yaml`. Battery is read fail-open: if the UPS cannot be reached, the sync proceeds.
:::

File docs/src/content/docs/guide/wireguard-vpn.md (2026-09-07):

---
title: "WireGuard VPN"
description: The built-in WireGuard client, its encrypted config, handshake-verified auto-connect, and the optional full tunnel that keeps local access.
---

The iOS Backup Machine ships a built-in WireGuard client. You upload a config through the web UI, it is stored encrypted, and a background reconciler brings the tunnel up automatically when a source you selected appears. The reconciler verifies a real WireGuard handshake, not just that the interface exists, and an optional full-tunnel mode routes all traffic through the VPN while keeping SSH and the web UI reachable from the LAN.

## Encrypted config

The config is uploaded through the web UI and stored encrypted at `/root/iosbackupmachine/wireguard.enc`. It is decrypted with the connected iPhone's serial or a custom passphrase. See [Security](../../architecture/security/) for how credential encryption works and how the two passphrase modes differ.

```yaml
wireguard:
  enabled: false
  interface_name: "wg0"
  auto_connect: false
  auto_connect_on: [iphone]
  full_tunnel: false
```

The interface defaults to `wg0`.

## Auto-connect triggers

Enable Auto-connect and pick the triggers: iPhone plugged in, WiFi available, and on boot. They are combinable. A background reconciler in the display daemon brings the tunnel up as soon as a selected connection source appears, so it connects reliably even after errors, reconnects, or a hotspot toggled on after the phone was already plugged in. It is not a one-off boot event.

```yaml
wireguard:
  auto_connect: true
  auto_connect_on: [iphone, wifi, boot]
```

### Handshake verification

The reconciler verifies that the tunnel actually handshakes, not just that the `wg0` interface exists. It re-checks every 10 seconds and tolerates an interface that is up without a handshake for 45 seconds; past that it tears the tunnel down and reconnects. Two common causes of a missing handshake:

- The endpoint is unreachable
- The clock is not yet NTP-synced, so the peer rejects the handshake

:::tip
Because a wrong clock breaks the handshake, keep NTP enabled. See [Networking](../networking/) for NTP sync over WiFi or the iPhone hotspot.
:::

### udid decryption mode

In `udid` decryption mode the config is decrypted with the iPhone serial, so the tunnel can only come up while the iPhone is readable. While it waits for the phone, the persisted WireGuard log lines show:

```text
Cannot decrypt: no iPhone connected
```

The iPhone must be trusted and readable for this, which the e-ink iPhone icon shows at a glance. See [Device connectivity](../../architecture/device-connectivity/) for how readability is detected.

## Full tunnel

Full tunnel is optional. It routes all traffic through the VPN and is re-applied on every connect. Use it when the remote sync server's IP overlaps the local WiFi subnet: a plain `wg-quick` full tunnel would send that same-subnet traffic out the WiFi instead of the tunnel. It requires `AllowedIPs = 0.0.0.0/0` in the WireGuard config.

```yaml
wireguard:
  full_tunnel: true
```

### Local access is preserved

Even with full tunnel on, SSH and the web UI stay reachable from the local network. Replies to connections that arrive on a non-VPN interface are kept off the tunnel via connection-mark policy routing (iptables `CONNMARK` plus an `ip rule`), while everything the device initiates still goes through the VPN.

## Status

WireGuard status is shown on the dashboard, the e-ink VPN icon, and `GET /api/status`. The VPN icon is crossed out with a "/" when the tunnel is inactive.

## Related

- [Security](../../architecture/security/) for credential encryption and passphrase modes
- [Device connectivity](../../architecture/device-connectivity/) for how iPhone readability is detected

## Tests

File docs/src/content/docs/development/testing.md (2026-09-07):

---
title: "Testing"
description: What the pytest suite covers, why it needs no e-paper hardware, how to run it, and the CI setup.
---

The project has a pytest suite covering the parts of the app that parse, encrypt, migrate, and decide, and also the display daemon, the web UI, and the e-paper HAL themselves, with no e-paper panel, PiSugar UPS, or iPhone involved anywhere. The tests import the flat app modules through a path shim, so they run on any machine. This page lists what the suite covers, how to run it, and how continuous integration runs it on every push and pull request.

## What the suite covers

The tests live under `tests/`, one file per area:

- rsync progress parsing (`test_sync_progress.py`): `sync_manager.parse_progress_line` reading rsync `--info=progress2` output into bytes, percentage, speed, and computed total, including the no-match and zero-percent cases
- Remote-sync credential crypto (`test_sync_crypto.py`): encrypt and decrypt round-trips for `sync_crypto`, wrong-passphrase and missing-file returning `None`
- WireGuard credential crypto (`test_wg_crypto.py`): `wg_crypto` AES-GCM round-trip plus the XOR fallback when `cryptography` is unavailable, deterministic 32-byte key derivation, and passphrase resolution across explicit, UDID, and custom modes
- Webhook auth credential crypto (`test_notify_crypto.py`): `notify_crypto` round-trip, the webhook auth header assembly, and the `_send_webhook` (status, error) contract
- Config schema and migration (`test_config_schema.py`): defaults filling, existing values winning while sibling defaults still fill, input not mutated, atomic save/load round-trip under concurrency, a wrong-typed or null value falling back to its default with a warning while a corrupt or non-mapping file reads as degraded and is backed up, and each migration in turn: the WiFi networks seeded from the legacy single `ssid`/`password`, the `backup_stale` event reaching devices that already had notifications configured without touching a deliberately narrowed list, and the old hard-coded one-hour sync cap being cleared while a deliberately chosen one survives
- WiFi netplan generator (`test_wifi_manager.py`): `wifi_manager.build_netplan` producing valid netplan YAML, skipping blank SSIDs, quoting special characters, and setting the high WiFi route metric so the iPhone hotspot is preferred
- Power-aware battery logic (`test_power.py`): PiSugar reply parsing and `power.sync_allowed`, covering fail-open on an unreadable UPS, charging bypassing the threshold, and low battery refusing
- SSH host key pinning (`test_host_key.py`): `host_key` fingerprint normalization across the forms a user might paste (canonical, bare base64, padded, mixed case, a whole `ssh-keygen -lf` line), rejection of MD5 and malformed values, `ssh-keygen -lf` output parsing, match selection among several offered keys, the pinned `known_hosts` being owner-only and holding only the matching key, and the fail-closed mismatch / no-key / missing-tool paths
- Host key pinning wired into sync (`test_sync_host_key.py`): `_prepare_sync` and `test_connection` leaving the ssh options untouched when no fingerprint is configured, pinning `StrictHostKeyChecking=yes` against the verified file when one is, aborting before rsync or ssh runs on a mismatch, and cleaning up both temp files afterwards
- Screen-handover policy (`test_uipolicy.py`): `uipolicy.should_release_hold` deciding when the post-backup result screen may be given up, and the `InfoWindow` lifetime, single-shot restore, re-tap extension, cancellation, and resume merge
- Display wiring (`test_display_wiring.py`): the daemon's actual info-screen paths: updates held back and queued while a tap is showing, the queued screen landing on resume, a backup cancelling the window and its queue, and a tap during a sync showing info then handing the sync screen back. It imports `iosbackupmachine.py` for real, stubbing `waveshare_epd` (which ships with the panel) and `python-periphery` only when the real package cannot import, and skipping entirely if the import still fails
- Log retention, capping and line stamping (`test_logutil.py`): `logutil.prune_logs` keeping the newest N per kind, dropping files past max age, leaving non-per-run logs alone, enforcing the aggregate per-kind size cap oldest-first while never deleting the log being written, and never raising on a missing directory; the per-file cap suppressing output, announcing itself, keeping the run's last lines for the close, counting bytes already on disk on a reopen, and never letting a write raise even when the disk is full or read-only; `wg_manager.latest_handshake` parsing the newest WireGuard handshake timestamp; and `logutil.stamp_stream` prefixing shell-produced log lines with the same stamp the per-run logs use, stripping ANSI colour and leaving blank lines blank
- Sync log content and the failure payload (`test_sync_logging.py`): the three-way split of rsync's merged output into file names, progress samples and messages; the rolling rate window returning no ETA rather than a fabricated one when nothing is moving; the throttled progress writer's line content, its percentage-change and interval triggers, and the once-a-minute file sample; the `[CMD]` line masking an sshpass password; every failure reason code producing a message; and the post-mortem probes composing, skipping what has nothing to say, and surviving one that raises
- Daemon hardening (`test_daemon_hardening.py`): the largest file in the suite, covering the loop watchdog's stall verdict and exit code, the fatal-error exit paths, the drop to a headless panel after a streak of draw failures and the backoff that climbs back out of it, the pre-backup mount, free-space and battery gates, the in-run health probe's mount / disk / battery verdicts and their debounce rules, the backup completion check, and the quiet-device staleness verdict and its clock guards. Like `test_display_wiring.py` it imports the real daemon against a throwaway config and runtime directory
- Web UI fail-safe behavior (`test_webui_failsafe.py`): the global error handler rendering a 500 page instead of a Werkzeug traceback, a degraded config showing the banner and re-engaging the setup wizard, the upload size cap, the import reporting what it reset, the bounded log viewer and its streamed download, the journal viewer, the refuse-then-override flow for reboot, shutdown and update (including a broken busy probe never trapping the owner and the quiesce wait staying bounded), the health endpoint's stale-backup warning, the sync time limit round-tripping through the form in minutes, and web-launched syncs detached from `webui.service`'s cgroup so a restart cannot kill the rsync
- Sync launcher guards (`test_backup_sync_guards.py`): `backup-sync.py`'s mutex guards failing closed, so a probe that cannot run (a missing `pgrep`, an unparseable status file) reads as "assume busy, skip" rather than silently disabling the guard; every probe passing a timeout so it can actually reach a verdict; and no guard writing the status file, which used to clobber a running backup's own state
- System update launch (`test_system_update.py`): the updater running in its own transient systemd unit rather than as a child of `webui.service`, the non-interactive and auto-reboot flags reaching it, its output landing in `update.log` stamped line by line, the exit status surviving the stamper pipeline, paths with spaces quoted for the inner shell, the fallback to a bare `bash` where `systemd-run` is absent, and the updating sentinel the display daemon watches
- Webhook auth cache (`test_notify_auth_cache.py`): a resolved header being cached and answering once the phone is gone, the three-way distinction between no auth configured, a header, and auth configured but unobtainable, the cache file and directory being owner-only under `/run`, only the header being cached and never the passphrase, TTL expiry, priming while the phone is attached, and the webhook being skipped rather than sent unauthenticated
- Notification delivery (`test_notify_delivery.py`): `flush()` waiting for in-flight deliveries and timing out rather than hanging, the `atexit` registration saving a caller that forgets to flush, the pending list staying bounded, and a non-mapping notifications, webhook or mqtt section reading as disabled instead of raising
- e-paper HAL (`test_epdconfig.py`): `epdconfig` against a fake gpiochip, covering a re-init while the lines are still held (the driver calls `module_init()` from both `init()` and `init_fast()`), every line being released when an init fails part-way, an optional power pin that may be absent, and the stuck-BUSY timeout firing only on a real stall
- Network probes (`test_netutil.py`): every `netutil` probe failure still returning its safe default (`{}`, `None`, `False`) and now logging the reason instead of failing silently
- WireGuard status (`test_wg_manager.py`): `latest_handshake` distinguishing "never handshaked" (zero) from "could not be read" (`None`) across a command error, a missing `wg`, and a timeout, plus `stop_wireguard` warning when the full-tunnel rules cannot be cleared

## Hardware-independent by design

The app ships flat to `/root/iosbackupmachine/` on the device and imports its siblings by bare name (for example `import sync_manager`). The tests mirror that layout with a path shim in `tests/conftest.py`, which puts `app/` on `sys.path` so the same bare-name imports resolve. Nothing in the suite touches the e-paper display, the PiSugar UPS, or a connected iPhone, so the tests run unchanged on a developer machine or in CI.

Most modules are import-safe by design so they can be tested this way: logic that would otherwise sit inline in the display daemon lives in `config_schema.py`, `logutil.py`, `power.py`, `host_key.py`, `netutil.py`, and `uipolicy.py`, which depend only on the standard library.

Three files import a real entry point rather than a helper. `test_display_wiring.py` covers the screen-handover wiring and `test_daemon_hardening.py` covers the watchdogs and guards; both import `iosbackupmachine.py`, stubbing `waveshare_epd` and `python-periphery` only when the real packages cannot import on this machine, and skipping the whole module if the import still fails. `test_webui_failsafe.py` imports `webui.py` against a throwaway config and skips when Flask is absent. `test_epdconfig.py` exercises the e-paper HAL itself, against a fake gpiochip rather than the panel.

## Run the tests

Install the runtime and test dependencies, then run pytest from the repository root:

```bash
pip install -r requirements.txt -r requirements-dev.txt
pytest
```

`requirements-dev.txt` adds only the test dependency (pytest); the runtime dependencies come from `requirements.txt`. See [Contributing](../contributing/) for the full local setup.

## Continuous integration

CI runs on GitHub Actions from `.github/workflows/ci.yml`. On every push and pull request it installs the same dependencies and runs `pytest -q` against a matrix of Python 3.11, 3.12, and 3.13. The matrix does not fail fast, so a failure on one Python version still reports the results for the others.

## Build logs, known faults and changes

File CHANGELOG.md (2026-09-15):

# Changelog

All notable changes to this project are documented here. The format follows
[Keep a Changelog](https://keepachangelog.com/en/1.1.0/), and the project uses a
single version constant in `app/webui.py`.

## [4.11.1] - 2026-09-15

### Fixed

- The web UI was unreachable for the first two minutes of every boot.
  `webui.service` ordered itself after `network-online.target`, which took 127 s
  to activate on the appliance, and the unit started the same second the target
  did, on its first attempt, with nothing wrong. That ordering was load-bearing
  while the bind address was resolved once at startup: starting before the
  network was up meant binding the wrong address permanently. The bind
  supervisor added in 4.11.0 re-resolves on a timer, so the wait now buys
  nothing and the dependency is gone.
- A finished or failed install left the e-ink claiming an update was still
  running. `install.sh` never cleared the sentinel the web UI drops before
  launching the updater, and only a reboot removes it from the runtime dir, so
  an install that ended without one left the panel lying until the display
  daemon's 30 minute safety valve expired. The installer's existing exit handler
  now clears it on every path out, and deliberately not when a reboot is coming,
  because the panel is meant to hold that frame across the reboot.
- An install that failed its health checks still recorded its reboot epoch.
  `.installed_version` was already withheld in that case, to mark the install
  unfinished, but `.reboot_epoch` was written unconditionally a few lines later.
  The next update compared against it, concluded no reboot was owed, and never
  asked again for the one the failed install still needed. Both files are now
  written under the same guard.

### Added

- Structural tests over `install.sh` and the shipped systemd units
  (`test_install_contract.py`, `test_service_units.py`). They assert invariants
  rather than run the scripts, which need root and a package manager: that the
  epoch write sits inside the health guard, that there is exactly one `EXIT`
  trap, since a second silently replaces the first and its cleanup never runs,
  and that the web UI does not reinstate the network-online ordering.

## [4.11.0] - 2026-09-15

### Fixed

- `webui.bind_interfaces` is a multi-select in the settings UI, but the code
  bound the first selected interface that happened to have an IP and ignored
  every other one. A device set to `usb_iphone` + `wireguard` served the web UI
  on the iPhone hotspot address alone and the WireGuard entry never took
  effect. The UI now listens on every selected interface that has an address.
- The bind address was resolved once at startup and never again. An interface
  that came up later was never served, and one that went away left the UI
  listening on an address that no longer existed. Neither is visible from
  outside: the process stays healthy and systemd sees no failure, so the only
  symptom is a browser that times out while SSH into the same device still
  works. A supervisor now re-resolves the selection every 20 s and binds and
  unbinds as addresses appear and disappear. A listener that survives a pass is
  left alone, so open connections are not dropped every interval.
- A selection that resolved to no address at all silently fell back to
  `0.0.0.0`, which discarded the restriction the operator had configured. It
  now binds nothing, logs one warning naming the selection, and starts serving
  the moment an address appears. A listener that cannot bind, a stale address
  still in the interface list, no longer aborts the addresses that can.

### Changed

- Every bind and unbind is logged, so `journalctl -u webui` names each address
  the UI is actually listening on instead of the single host it started with.

## [4.10.3] - 2026-09-07

### Fixed

- A flaky test broke CI. `test_the_quiesce_wait_is_bounded` counted every value
  passed to `time.sleep` while the reboot route ran, but monkeypatching
  `webui.time.sleep` replaces it for the whole process, so the background
  connectivity monitor's 20 s tick was counted as a quiesce poll whenever an
  earlier test had started that thread. It passed on Windows, where the tests
  that start it are skipped, and failed on Linux. The assertion now counts only
  sleeps of `_QUIESCE_POLL_SEC`, which is a named constant for exactly that
  reason. No production behaviour changed.

## [4.10.2] - 2026-09-07

### Fixed

- The journal viewer's problems-only filter matched the two daemons' bracket
  tags only. Flask leaves its `default_handler` on `app.logger`, so every
  `app.logger.warning` and `.error` also reaches `webui.service`'s journal
  formatted `[ts] WARNING in webui: ...`, which none of those tags match: the
  filter answered "nothing matched" on a journal full of web UI errors.
- That filter also dropped the flood-truncation notice, so a filtered view of a
  truncated window read as the whole story.
- `prune_logs` promised the freshest log survives all three of its rules, and
  the size sweep spared it, but the age rule did not. An appliance idle past
  `IOSBACKUP_LOG_MAX_AGE_DAYS` could delete the log the daemon still held open,
  freeing nothing and making the live run vanish from the Logs page.
- Cancelling a sync to reboot, shut down or update wrote no closing line to the
  persistent sync log, so the confirm banner's promise that "the run log records
  why it ended" held for a backup and not for a sync.
- A clean stop that failed or ran out of budget still reported success. The
  caller now says the log may end without a reason instead of leaving the
  failure in `webui.log` alone.
- The journal page re-read the boot count from journald on every render, and its
  live tail re-renders every 10 s, so a tab left open forked `journalctl` twice
  per refresh for an answer that does not change.

### Added

- Tests for `Panel`, the only writer to the e-ink panel and the one class the
  suite never constructed. Covers the errno-16 retry that the blank-display bug
  disabled, and the driver API resolution whose silent failure mode is a correct
  picture that flashes on every tick.

## [4.10.1] - 2026-09-07

### Fixed

- `sync.allowed_ssid` was missing from the config schema, so it was never
  default-filled and never type-checked: the settings page wrote it and
  `sync_manager` read it, but a hand-edited non-string reached the SSID
  comparison instead of being reset with a warning like every other setting.
  Found while auditing the documentation against the code.

### Changed

- Documentation brought back in line with the code across all 18 pages, the
  README, `SECURITY.md`, `CONTRIBUTING.md` and `config.yaml.example`. Several
  statements were wrong rather than merely out of date, the backup battery
  threshold and the manual-install paths among them.

## [4.10.0] - 2026-09-07

### Fixed

- The overall sync time limit was a hard-coded 3600 s that nothing in the web UI
  could change, so a first sync of a large backup set aborted mid-transfer and
  reported a failure. A 130 GB set stopped at 20% after an hour. There is now no
  default limit at all: the scan and stall watchdogs already abort a sync that
  has stopped moving, so a cap only bounds one that is still working. Existing
  configs holding the old 3600 are cleared on upgrade; any other value was
  chosen deliberately and is left alone.

### Added

- A **Time limit** field in Remote Sync settings, in minutes, empty for no
  limit. Anything unparseable reads as no limit rather than silently
  reinstating a cap.

### Changed

- Config schema version 4, for the sync-limit default.

## [4.9.0] - 2026-09-07

### Fixed

- A fatal error in the display daemon exited with code 0, so systemd's
  `Restart=on-failure` never restarted it - one unexpected exception left the
  device dead until the next power cycle. Fatal exits now use a non-zero code
  and the unit restarts the daemon.
- The daemon no longer dies or hangs on startup faults: an unwritable log
  directory, a missing or stuck e-ink display, or a broken config all degrade
  instead of crashing - the daemon runs headless (backups, sync and
  notifications keep working) and logs one journal warning. The e-ink BUSY wait
  now has a 10-second ceiling instead of blocking forever, and after 30
  consecutive draw failures the panel is re-initialised once. Headless is never
  final: while the display is unavailable the daemon retries it on a 30 s to
  15 min backoff, so a panel that was only slow to appear at boot recovers on
  its own instead of staying dark until a restart.
- A hung backup is no longer invisible: `idevicebackup2` is terminated after
  600 s without output (`backup.hang_timeout_sec`) and capped at 4 h total
  (`backup.max_duration_sec`), `idevice_id`/`idevicepair`/`df`/`pgrep` probes
  have timeouts, and a watchdog thread restarts the daemon if the main loop
  stalls. An unplugged phone is now detected within 30 s even if both udev and
  `idevicebackup2` misbehave.
- `systemctl stop iosbackupmachine` no longer orphans a running
  `idevicebackup2` (`KillMode=mixed`), and the daemon terminates a running
  backup child before exiting.
- A corrupt or truncated `config.yaml` no longer bricks the web UI and every
  route in it: the bad file is saved as `config.yaml.bad-*`, the device runs on
  defaults with a banner in the web UI, and the first-start wizard re-engages
  (previously a missing config silently disabled the web UI password). Config
  values with the wrong type are replaced by defaults with a warning instead of
  crashing pages. Concurrent saves no longer race, and the directory is fsynced
  after the atomic rename.
- The web UI gained a global error handler (friendly page instead of a bare
  500), every settings save is guarded, and syncs started from the web UI now
  survive a web UI restart (launched via `systemd-run`, like the updater).
  Purging logs no longer deletes the web UI's own open log file.
- Logging can no longer crash what it logs: a full or read-only disk makes the
  log writer degrade to the journal instead of raising into callers - including
  the daemon's own fatal-error handler. Per-run logs now have a 100 MB per-kind
  size cap in addition to the count/age pruning.
- `send_notification` and the credential decrypter no longer raise on malformed
  config or corrupt `.enc` files; they degrade to "no credentials/disabled".
- Sync launcher guards now fail closed (a failed probe skips the sync instead
  of allowing overlapping rsync/backup runs), skipped syncs write a
  `sync_skipped` status instead of leaving stale state, and a failed sync exits
  non-zero. Syncs now have an overall time cap (`sync.max_seconds`, default
  1 h) in addition to the stall watchdog.
- WireGuard: a `wg` command error is no longer indistinguishable from "no
  handshake yet", so the reconciler stops cycling the tunnel every minute when
  the probe itself fails; full-tunnel enforcement failures are reported instead
  of swallowed. WiFi: a failed netplan rollback is now reported ("WiFi may be
  down") instead of ignored, and clearing all networks reports real failures.
- A failed or interrupted upgrade no longer leaves the appliance dead: when the
  installer aborts after stopping services, it restores the previous install
  from its backup and restarts the web UI and daemon. The version file is only
  written when the health checks pass. The storage marker file is only created
  when the backup drive is actually mounted, so backups can no longer silently
  land on the root filesystem.
- Backups now refuse to start when disk space is critically low (previously a
  warning that was ignored) or when the backup storage is read-only, with a
  clear display/status message instead of a mid-backup failure.
- `usbmux-refresh.sh` checks and retries the usbmuxd restart; the WireGuard
  auto-connect script is serialized with `flock` so the boot service and the
  NetworkManager dispatcher can no longer race; rtc-sync output now reaches the
  web UI logs page.

- Reboot, shutdown and a system update no longer destroy work in flight. They
  were the only actions with no mutual exclusion at all, while starting a sync
  during a backup was already refused. Each now refuses once, names what is
  running and how to stop it, and offers an explicit override that stops the work
  through the sanctioned path first, so the run log still records why it ended.
  The check fails open, so a device that cannot answer "is a backup running" can
  always still be powered off.
- The log viewer could take the web UI down. It read the whole file and rendered
  it in full, and nothing capped a single run log, so the page opened when
  something had gone wrong was at its most dangerous when it was most needed. It
  now shows a bounded head and tail and says so, with a streamed download for the
  whole file, and the writer caps a single run, marks where it cut and appends the
  closing lines when the run ends. The daemon's own backup log is capped too - it
  is one file for the whole daemon lifetime, not one per backup.
- A backup had no battery protection, though a sync had it at both ends. A run
  starting at 33% was powered off mid-write by PiSugar's own 30% auto-shutdown.
  It now refuses below `backup.min_battery_percent` (default 35) and aborts if
  the battery falls during the run.
- The backup drive disappearing mid-run left `idevicebackup2` filling the rootfs
  through the empty mountpoint. The marker that distinguishes a mounted drive
  from an empty directory was only checked before the run; it is now checked
  every 10 s, alongside the device id of the mountpoint, and a lost drive is
  killed without the usual SIGTERM grace.
- Free space was measured once, against a 500 MB floor, for a job that writes
  tens of gigabytes - so the run died on ENOSPC deep in. It is now checked during
  the run against `backup.min_free_mb`, and the start floor rises with it so a
  run can never pass the gate and then abort on its own first poll.
- The completion check only tested that `Manifest.plist` parsed, which an
  interrupted run passes because the previous run's copy is still there. It now
  tests signals that actually prove a run finished, degrading to the old answer
  on a layout it does not recognise: calling a good backup bad would be worse.
- Uploads had no size limit, and a config import silently reset wrong-typed
  values. Uploads are now capped and the import says what it corrected.

### Added

- `ntp-sync.timer`: retries clock sync 2 min after boot and every 15 min after
  that (once synchronized, each run is one cheap early-exit probe) - a boot
  without internet no longer leaves the clock wrong forever (which broke
  WireGuard handshakes).
- A journal viewer in the web UI. Much of the daemons' diagnostics go to the
  systemd journal rather than to a log file - panel failures, watchdog trips, a
  stalled main loop - so that whole class of degradation was invisible from the
  device's own interface. The Logs page now links to a viewer over the units that
  matter, honest about how far back the journal goes on an appliance whose
  `/var/log` is a RAM disk.
- A `backup_stale` notification. Every other event is edge-triggered, so an
  appliance that quietly stopped backing up told nobody until a restore was
  needed. A durable last-success record now drives one alert per quiet episode
  (`backup.stale_after_sec`, default 7 days, `backup.notify_stale` to disable),
  with the state also on the panel and the health endpoint.
- New `backup:` settings, all file-only for now: `min_battery_percent`,
  `min_free_mb`, `notify_stale`, `stale_after_sec`.

### Changed

- Config schema version 3. The migration adds `backup_stale` only to
  notification event lists that already asked for `backup_error`: a list
  narrowed to successes is a deliberate choice, and adding the event to the
  defaults alone would have reached fresh installs only, never the devices that
  would benefit.

## [4.8.1] - 2026-09-02

### Fixed

- After a failed backup, "Start Backup" in the web UI did nothing while the
  error screen was up, and the request then fired later when the iPhone was
  next plugged in - looking like an unwanted automatic backup. One cause, two
  symptoms: the error screen's wait polled only for the cable being pulled, so
  the daemon was deaf to everything else for as long as the phone stayed in.
  The web UI meanwhile reported the request accepted, and the sentinel that
  carries it stays valid for 15 seconds, so a replug inside that window ran the
  backup the user had asked for a minute earlier.

  The wait now releases on the same three conditions as the post-backup hold -
  the phone leaving, a fresh manual request, or shutdown - and does so by
  calling the same `uipolicy.should_release_hold` rather than keeping its own
  copy of the rule, which is how the two drifted apart in the first place.

## [4.8.0] - 2026-09-02

### Added

- Sync failures now carry a structured, stable payload instead of a sentence.
  Every way a sync can fail maps to one of a fixed set of `reason_code` values
  (`ssh_connection_failed`, `stall_timeout`, `out_of_memory`, `battery_abort`
  and so on), and the failure object carries the exit code, how far the transfer
  got in bytes and percent, its duration, the last file rsync was on, and the
  post-mortem findings. The same object is the `[ERROR]` line in the log, the
  message on the e-ink and the dashboard, and the `sync_error` notification body
  delivered over MQTT and webhook - so the three can no longer disagree. The
  payload keeps `error` alongside `message` so an existing consumer still works.
- A failed sync now runs a post-mortem and records it in the log and in the
  notification: whether the kernel OOM killer took rsync, whether the remote
  answers on its SSH port now, how long ago WireGuard last handshook, and free
  space on the source. When rsync dies mid-transfer it often prints nothing at
  all, and these are the facts that are gone by the time anyone looks. Each
  probe is best-effort: one that cannot run says so, and the rest still report.
- Sync progress lines now carry bytes transferred against the total, speed,
  elapsed time, an ETA, and the byte delta since the previous line. The delta is
  what distinguishes a transfer parked on one percentage but still moving from
  one that is genuinely stuck. The ETA comes from a rolling ten-minute average
  of the transfer's own samples rather than rsync's instantaneous rate, and
  reads `ETA unknown` rather than guessing when nothing is moving. It is also
  shown on the dashboard's Remote Sync card.
- Sync logs now name the file rsync is on (`--out-format`), sampled at most once
  a minute, so a failure can be pinned to a file rather than to a bare
  percentage. rsync reports every file it sends, which on a first sync is six
  figures of them, so the log keeps a sample rather than the list. Directories
  and symlinks are filtered out by rsync's own itemize flag: rsync reports those
  through the same channel and creates them instantly, so one would otherwise
  displace the real file at the moment it matters. `--stats` appends the real
  totals when a run ends.
- A Network card on the dashboard: internet reachable or not, which link is
  carrying it (WiFi with its nickname, or the iPhone's USB hotspot), WireGuard
  up or down, and how long the current state has held. The appliance switches
  links on its own, so how long the current one has lasted is worth showing next
  to whether it is up. The probe runs on its own schedule and the page reads a
  cached answer, so polling it every 5 seconds costs nothing; `/api/health` reads
  the same cache and falls back to a direct probe when it is stale.
- `update.log` and the sync output redirected into `autostart.log` are now
  timestamped line by line, through a `logutil.py --stamp` filter that reuses the
  format the per-run logs already use. They were the last two logs whose lines
  could not be lined up against the others.

### Changed

- The sync log is now written entirely by `sync_manager`; the auto-sync (display
  daemon) and the manual sync (`backup-sync.py`) no longer format their own
  progress lines and can no longer drift apart. They drive the e-ink and the
  status file only.
- Sync progress is logged once a minute rather than every 30 seconds. The lines
  carry considerably more, and an eight-hour transfer now leaves a log in the
  low hundreds of lines instead of around a thousand near-identical ones.

### Fixed

- Webhook notifications were sent unauthenticated whenever the iPhone was not
  attached, and an authenticated endpoint answered 403 with no trace anywhere.
  The auth header is decrypted with the iPhone's serial number, but most of the
  events that carry it fire when the phone is gone: `device_disconnected` by
  definition, every `sync_*` after the phone was unplugged, and `backup_complete`
  - which is sent only after the e-ink has already displayed "Backup completed"
  and invited the user to unplug. `webhook_auth_headers` reported that failure as
  `{}`, indistinguishable from "no auth configured", so the request went out
  regardless.

  The resolved header is now cached in `/run/iosbackupmachine/webhook_auth.json`
  (0600 in a 0700 directory) and reused when the phone is absent. `/run` is a
  systemd tmpfs: RAM-only, wiped at every boot, never written to the SD card - so
  a powered-off device still yields nothing without the phone. Only the derived
  header is cached, never the passphrase, which is the phone's serial and also
  unlocks the WireGuard and remote-sync credentials. The cache is refreshed
  whenever the phone is seen, primed at the start of every backup, dropped when
  notification settings are saved, and can be given a lifetime with
  `IOSBACKUP_WEBHOOK_AUTH_TTL` (default 0, meaning until the next reboot).

  When auth is wanted and genuinely unobtainable the webhook is now skipped
  rather than sent blind, and the reason is written to the per-run log the web UI
  serves - on the Test Webhook button too, which calls the sender directly and
  needed the same check. Delivery failures - a 403, a refused connection, a
  missing paho-mqtt - now land in that log as well, instead of only in the
  journal.

- Notifications sent by a manual sync were silently discarded. `send_notification`
  dispatches webhook and MQTT deliveries on daemon threads and returns at once,
  and `backup-sync.py` calls `sys.exit(0)` immediately after reporting its
  result. Python terminates daemon threads at interpreter exit, so the POST was
  killed mid-request, every time, with no error recorded anywhere. Deliveries are
  now tracked and `notifications.flush()` waits for them; it is also registered
  with `atexit`, which runs before daemon threads are killed, so a caller that
  forgets to flush is still covered. Affected every sync started from the web UI,
  a long press or a double tap, and the low-battery refusal. The auto-sync after
  a backup was not affected, because the display daemon keeps running.

### Security

- The `[CMD]` line in a sync log published the SSH password in clear for
  password-authenticated syncs: the full argv was written verbatim, and for that
  auth method the argv is `sshpass -p <password> ...`. The log is served by the
  web UI at `/logs/<file>`, so anyone who could read a log could read the
  password. The password is now masked. Key-authenticated setups were never
  affected. Rotate the remote's password if you used password auth and any sync
  log may have been seen.

## [4.6.0] - 2026-08-31

### Fixed

- An update started from the web UI killed itself partway through and took the
  device off the VPN. The updater ran as a plain child of `webui.service`;
  `install.sh` restarts that unit midway, and since the unit does not set
  `KillMode=process`, systemd tore down its whole control group - the updater
  with it. `start_new_session` had put the updater in its own session but not
  its own cgroup, so it was no protection. The kill landed after the installer
  had stopped every service and before it restarted any, leaving the display
  daemon down and, with it, the WireGuard reconciler that keeps the VPN up. The
  updater now runs in its own transient systemd unit (`systemd-run
  --unit=iosbackup-update --collect`), outside the web UI's cgroup, so
  restarting the web UI cannot touch it.
- A web-triggered update never rebooted, even when the release required one.
  Both `update.sh` and `install.sh` asked with `read -rp`, which reads EOF
  without a tty and takes the "no" branch - so "Re-install anyway?" silently
  cancelled a re-install and "Reboot now?" silently skipped the reboot. Both
  prompts now honour `IOSBACKUP_NONINTERACTIVE=1`.

### Changed

- An update started from the web UI now always reboots the device when it
  finishes (`IOSBACKUP_AUTO_REBOOT=1`), rather than only when the release bumps
  `REBOOT_EPOCH`. The installer stops every service up front and restarts only
  some of them, so a reboot is what guarantees the display daemon, the
  WireGuard reconciler and usbmuxd all come back. Updates run over SSH are
  unchanged and still prompt.

### Added

- An `Updating - device will reboot` screen on the e-ink for the duration of a
  web-triggered update. The web UI drops a sentinel before it launches the
  updater; the display daemon shows the screen while it exists and paints it as
  its final frame on the way down, so the e-ink holds it with the daemon
  stopped and through the reboot. Without this the daemon's shutdown handler
  painted the power-off owner screen, which reads as "the device is off" for
  the whole update. The sentinel is retired once it predates the current boot
  (armbian-ramlog restores zram `/var/log` across a reboot, so it cannot be
  assumed to vanish with it), and in any case after 30 minutes, so an update
  that dies without rebooting cannot strand the panel.

## [4.5.1] - 2026-08-21

### Fixed

- The sync screen showed a total size that kept moving up and down for the
  whole transfer. rsync's `--info=progress2` reports only an integer
  percentage, and the total was back-computed from it as `bytes * 100 / pct`,
  so the figure climbed while the transferred bytes grew inside one percent
  bucket and dropped again each time the percentage ticked over - an error of
  up to `total/pct`, so roughly a factor of two at 1% and still a few percent
  at half way. The real total is now measured by walking the backup directory
  on a background thread while rsync builds its own file list, so it is
  normally exact from the first progress update and never moves afterwards.
  The old estimate is kept only as a fallback for the case where the walk
  fails or has not finished yet.
- Progress on the e-ink and the dashboard lagged behind the transfer. rsync
  separates its progress samples with CR, not LF, so a single read of the pipe
  holds a burst of ten or more of them; the parser took the first and dropped
  the rest, then took the first of the next burst. It now takes the newest
  sample in each burst, so the bytes, percentage and speed on screen are
  current.

## [4.5.0] - 2026-08-21

### Added

- Optional SSH host key verification for the sync server. Remote Sync settings
  gains a `Verify the server's SSH host key` switch and a SHA256 fingerprint
  field; when set, the device pins that key and refuses to sync if the server
  presents a different one. Verification runs before any data moves, on both
  Test Connection and every sync, and fails closed - a mismatch or an
  unreadable key aborts rather than falling back to trusting the server.
  `Fetch from server` reads the offered fingerprints so they can be compared
  against a value obtained out-of-band. Leaving the switch off keeps the
  previous `accept-new` behaviour unchanged.

### Fixed

- The e-ink could sit on a stale `Sync failed` (or other result) screen through
  an entire following sync or backup. After a backup the daemon holds the result
  screen until the iPhone is unplugged, but that wait watched only the cable, so
  it never re-read the status file - a sync started from the web UI while the
  phone was still plugged in, or a fresh backup request, stayed invisible for its
  whole run. The wait now also releases the screen for a live sync or an explicit
  start request. An idle plugged-in phone still holds the result, so the same
  device is not immediately backed up again.
- The single-tap system-info screen did nothing in the cases it was most wanted.
  A tap was discarded outright while a backup or sync was running - and the
  request flag was consumed anyway, so the tap vanished - and even when it was
  allowed, the next sync tick repainted over it about half a second later. A tap
  now always shows the info screen for 30s whatever the device is doing, and the
  screen that was up beforehand comes back when the window closes, along with
  anything the daemon drew meanwhile (so a backup result raised during those 30s
  is not lost). The rule is enforced once, in the display's single drawing owner,
  instead of at each call site.

## [4.4.4] - 2026-07-14

### Fixed

- A completed sync could be reported as failed with `rsync failed (exit None)`.
  The read loop broke on the output pipe's EOF before it ever reaped rsync, so
  the exit code was still unset when it was checked. rsync is now reaped after
  the loop, so the real exit status is used and a clean exit-0 is no longer
  misreported. This was a race, so it surfaced intermittently.

### Changed

- Sync logs are now wall-clock timestamped (`[YYYY-MM-DD HH:MM:SS]` per line),
  matching the continuous logs, instead of carrying only rsync's elapsed-seconds
  counter. Applies to both auto-sync and manual sync.
- A failed sync names the reason: the log and status now read e.g. `rsync failed
  (exit 255: SSH/connection error ...)` or `killed by signal 9`, instead of a
  bare exit number.

## [4.4.3] - 2026-07-08

### Fixed

- usbmux hot-plug now works for every plug and lock order. The daemon tracks a
  sysfs signature of the connected Apple device, so a fresh plug or a
  re-enumeration (from unlocking a phone that was in USB Restricted Mode)
  restarts usbmuxd immediately, and a device that stays invisible is retried
  with exponential backoff (8s to 120s) instead of on a tight loop.

### Changed

- The single-tap info screen shows the last sync time in the same format as the
  last backup time (`HH:MM / DD Mon YYYY`).

## [4.4.2] - 2026-07-08

### Fixed

- Hot-plugging an iPhone after boot is recognised without a udev round-trip. The
  usbmuxd re-scan moved into the always-on daemon, which restarts usbmuxd when
  the kernel sees an Apple device that usbmux does not.
- The single-tap PiSugar button shows the system-info screen again. The button
  now uses the same flag-file mechanism as double and long tap (the pisugar
  socket had no working single-tap query).

## [4.4.1] - 2026-07-07

### Added

- A udev rule and one-shot service that re-scan usbmuxd when an iPhone is
  plugged in, working around the libusb hot-plug gap on this image.

## [4.4.0] - 2026-07-07

### Added

- Three-state iPhone status icon: absent, plugged-but-untrusted (padlock), and
  trusted (checkmark), so the trust state that udid-mode decryption depends on is
  visible at a glance.

## [4.3.1] - 2026-07-07

### Fixed

- Status icons paint the true state on the first sample, so they are correct
  after a daemon restart instead of showing stale defaults.

## [4.3.0] - 2026-07-07

### Changed

- Logs persist on the rootfs under `/var/lib/iosbackupmachine/` so they survive
  reboots and power loss, with app-managed retention (newest 50 backup and 50
  sync logs, and anything older than 90 days pruned). Volatile runtime state
  stays on the zram `/var/log` to avoid SD-card wear.

### Fixed

- The WireGuard auto-connect reconciler verifies an actual handshake instead of
  just the interface existing, and tears down and reconnects a tunnel that comes
  up but never handshakes.

## [4.2.0] - 2026-06-08

### Changed

- WiFi backend rewritten on netplan and wpa_supplicant with multi-network
  roaming, status icons on every screen, and a full-tunnel VPN mode that keeps
  local SSH and web UI access.

[4.4.3]: https://github.com/giovi321/ios-backup-machine/compare/v4.2.0...v4.4.3
[4.2.0]: https://github.com/giovi321/ios-backup-machine/releases/tag/v4.2.0

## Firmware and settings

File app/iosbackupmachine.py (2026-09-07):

#!/usr/bin/env python3
import os, re, sys, time, json, glob, select, shutil, signal, subprocess, tempfile, threading
from datetime import datetime
from periphery.gpio import GPIOError

import yaml
from PIL import Image, ImageDraw, ImageFont
from waveshare_epd import epd2in13_V4, epdconfig

try:
    from notifications import send_notification
except ImportError:
    def send_notification(*a, **kw): pass

try:
    import netutil
except ImportError:
    netutil = None

try:
    import sync_manager as _sync_manager
except ImportError:
    _sync_manager = None

try:
    import config_schema as _config_schema
except ImportError:
    _config_schema = None

try:
    import wg_crypto as _wg_crypto   # iPhone presence / trust probe for the status icon
except ImportError:
    _wg_crypto = None

import uipolicy

CONFIG_PATH = os.getenv("IOSBACKUP_CONFIG", "/root/iosbackupmachine/config.yaml")
import logutil
# Logs are persistent (rootfs); runtime IPC stays on the volatile zram /var/log.
# See logutil.py for why they are split.
LOG_DIR = logutil.LOG_DIR
RUNTIME_DIR = logutil.RUNTIME_DIR
STATUS_FILE = os.path.join(RUNTIME_DIR, "backup_status.json")
# The durable record of a SUCCESSFUL backup. On LOG_DIR (persistent rootfs) and
# not RUNTIME_DIR, because backup_status.json lives on zram and main() overwrites
# it with "waiting" on every start — so it cannot answer the one question the
# quiet-device alert is built on ("when did a backup last succeed?"), which is
# precisely the question that has to survive a reboot. Written once per completed
# backup, not per progress tick, so it costs no meaningful SD wear.
LAST_BACKUP_FILE = os.path.join(LOG_DIR, "last_backup.json")
# Sentinels the web UI drops to drive the always-on daemon (which can no longer
# be started/stopped by restarting its service — that would kill the EPD owner).
START_FILE = os.path.join(RUNTIME_DIR, "start_requested")   # force a backup (auto-start off)
STOP_FILE = os.path.join(RUNTIME_DIR, "stop_requested")     # abort the current backup
INFO_FILE = os.path.join(RUNTIME_DIR, "info_requested")     # single-tap -> show system-info screen
# Dropped by the web UI before it launches the updater. The installer stops this
# daemon partway through, so the "Updating" screen has to be the LAST thing painted:
# e-ink holds it with no power to the panel, right through the reboot. The file
# lives on the volatile runtime dir, so a reboot clears it by itself.
UPDATING_FILE = os.path.join(RUNTIME_DIR, "updating")       # system update in progress -> reboot pending
UPDATING_MAX_SEC = 1800   # safety valve: an update that dies without rebooting
                          # must not strand the panel on "Updating" forever
IDLE_REFRESH_SEC = 4
WG_RECONCILE_SEC = 10   # how often the WireGuard auto-connect watcher re-checks
WG_HANDSHAKE_GRACE_SEC = 45   # tolerate 'up but no handshake yet' this long before re-connecting
DRAW_FAIL_REINIT_AFTER = 30   # consecutive draw failures before one panel re-init, then headless
PANEL_RETRY_MIN_SEC = 30   # first re-init attempt after dropping to headless
PANEL_RETRY_MAX_SEC = 900   # cap, so a unit built with no panel costs ~nothing
BACKUP_SILENCE_TIMEOUT_SEC = 600   # idevicebackup2 silent this long -> hung; terminate it
BACKUP_MAX_DURATION_SEC = 4 * 3600 # total cap for a single backup run
STALE_AFTER_SEC = 7 * 24 * 3600    # no successful backup for this long -> one alert
STALE_POLL_SEC = 900               # how often the quiet-device watcher re-checks
STALE_BOOT_GRACE_SEC = 900   # iosbackupmachine.service is ordered only After=
                             # local-fs.target usbmuxd.service, NOT after rtc-sync,
                             # and ntp-sync.timer first fires at OnBootSec=2min, so
                             # the clock can still be wrong minutes into a boot.
STALE_CLOCK_FLOOR = 1767225600   # 2026-01-01 UTC. A board with a dead RTC cell and
                             # no network boots reading 1970; anchoring the record to
                             # that clock makes the next tick compute an age of
                             # decades once NTP corrects it, and alert on a healthy
                             # device. Guarding the WRITE is what closes that.
TITLE = "iOS Backup Machine"

def _apply_defaults(cfg):
    cfg.setdefault("backup_dir", "/media/iosbackup/")
    cfg.setdefault("marker_file", ".foldermarker")
    cfg.setdefault("disk_device", "/dev/mmcblk1")
    cfg.setdefault("orientation", "landscape_right")
    cfg.setdefault("owner_lines", ["Name", "telephone", "email", "message"])
    cfg.setdefault("error_codes", {})
    cfg.setdefault("env", {})
    ec = {}
    for k, v in cfg["error_codes"].items():
        try: ec[int(k)] = str(v)
        except Exception: pass
    cfg["error_codes"] = ec
    return cfg

def load_config(path):
    with open(path, "r") as f:
        cfg = yaml.safe_load(f) or {}
    return _apply_defaults(cfg)

try:
    CFG = load_config(CONFIG_PATH)
except Exception as e:
    # A config that crashes the loader must not take the daemon down with it:
    # fall back to the schema defaults so backups can still run.
    print(f"[WARN] Could not load config {CONFIG_PATH} ({e}); using built-in defaults", flush=True)
    CFG = _apply_defaults(_config_schema.apply_defaults({}) if _config_schema else {})
for k, v in CFG.get("env", {}).items():
    os.environ[k] = str(v)

CUSTOM_FONT = CFG.get("font_path") or "/root/iosbackupmachine/UbuntuMono-Regular.ttf"

def font(sz):
    try:
        return ImageFont.truetype(CUSTOM_FONT, sz)
    except Exception:
        return ImageFont.load_default()

F_SM = font(12)
F_MD = font(12)
F_LG = font(12)
F_14 = font(14)

# Process-wide shutdown latch. The SIGTERM/SIGINT handler sets it; the Animator
# thread (the sole EPD drawer) notices it, paints the owner screen one last time,
# sleeps the panel so the image persists after power-off, and exits.
SHUTDOWN = threading.Event()


# ---------------------------------------------------------------------------
# Main-loop heartbeat watchdog. The main loop (and every long-running hold it
# can legitimately sit in: backup output, post-backup holds) calls _heartbeat();
# if no beat lands within stall_sec the process is wedged somewhere without a
# watchdog of its own, so we log and exit 1 — Restart=on-failure brings back a
# healthy daemon. Time and exit are injectable so tests can drive it without
# threads or os._exit.
# ---------------------------------------------------------------------------
class LoopWatchdog:
    def __init__(self, stall_sec, exit_fn=None, time_fn=None, log_fn=None):
        self.stall_sec = stall_sec
        self._exit = exit_fn or os._exit
        self._time = time_fn or time.monotonic
        self._log = log_fn or (lambda m: print(m, flush=True))
        self._last_beat = self._time()
        self._lock = threading.Lock()
        self._stop = threading.Event()
        self.thread = None

    def beat(self):
        with self._lock:
            self._last_beat = self._time()

    def check(self):
        """One watchdog pass; returns True when the loop proved stalled."""
        with self._lock:
            stalled = (self._time() - self._last_beat) > self.stall_sec
        if stalled:
            self._log(f"[FATAL] main loop stalled (no heartbeat for >{int(self.stall_sec)}s)")
            self._exit(1)
            return True
        return False

    def _run(self):
        while not self._stop.wait(5):
            if self.check():
                return

    def start(self):
        self.thread = threading.Thread(target=self._run, daemon=True)
        self.thread.start()

    def stop(self):
        self._stop.set()


_loop_watchdog = None

def _heartbeat():
    wd = _loop_watchdog
    if wd is not None:
        try: wd.beat()
        except Exception: pass


# ---------------------------------------------------------------------------
# Shared drawing helpers (folded in from the former standalone screen scripts:
# boot-message.py, button-info.py, owner-message.py, unplug-notify.py).
# The display service is now the single owner of the EPD — nothing else draws.
# ---------------------------------------------------------------------------

def draw_small_power_icon(drw, x, y, size=10):
    """Small power-on indicator (circle with stem)."""
    cx, cy = x + size // 2, y + size // 2
    r = size // 2
    drw.arc((cx - r, cy - r, cx + r, cy + r), start=300, end=240, fill=0, width=1)
    drw.line((cx, cy - r, cx, cy - 1), fill=0, width=1)


def draw_project_icon(drw, cx, cy, size=36):
    """1-bit project icon: rounded-rect outline + downward arrow."""
    half = size // 2
    x0, y0 = cx - half, cy - half
    x1, y1 = cx + half, cy + half
    drw.rounded_rectangle((x0, y0, x1, y1), radius=size // 6, outline=0, width=2)
    arrow_w = size * 2 // 5
    margin = size // 5
    drw.line((cx, y0 + margin, cx, y1 - margin), fill=0, width=2)
    head_y = cy + margin // 2
    drw.line((cx - arrow_w // 2, head_y, cx, y1 - margin), fill=0, width=2)
    drw.line((cx + arrow_w // 2, head_y, cx, y1 - margin), fill=0, width=2)


# ---------------------------------------------------------------------------
# Status icons (drawn on every live screen): power (always on) + vpn / internet
# / wifi / iphone, each crossed out with a "/" when inactive. Connectivity is
# sampled by a background thread (have_connectivity blocks on a socket test) and
# cached, so the draw path never does network I/O.
# ---------------------------------------------------------------------------
STATUS_BAR_H = 14   # vertical space the icon row reserves at the bottom of a screen

_icon_status = {"vpn": False, "internet": False, "wifi": False, "iphone": "absent"}
_icon_status_lock = threading.Lock()


def _icon_slash(drw, x, y, sz):
    """Diagonal '/' through an icon to mark it inactive."""
    drw.line((x - 1, y + sz, x + sz, y - 1), fill=0, width=1)


def draw_icon_vpn(drw, x, y, sz=10, on=True):
    """Minimal padlock = VPN."""
    drw.arc((x + 2, y, x + sz - 2, y + sz - 1), start=180, end=360, fill=0)        # shackle
    drw.rectangle((x + 1, y + sz // 2, x + sz - 1, y + sz), outline=0, width=1)    # body
    if not on:
        _icon_slash(drw, x, y, sz)


def draw_icon_internet(drw, x, y, sz=10, on=True):
    """Minimal globe = internet."""
    drw.ellipse((x, y, x + sz, y + sz), outline=0, width=1)
    drw.line((x, y + sz // 2, x + sz, y + sz // 2), fill=0, width=1)               # equator
    drw.ellipse((x + sz // 3, y, x + sz - sz // 3, y + sz), outline=0, width=1)    # meridian
    if not on:
        _icon_slash(drw, x, y, sz)


def draw_icon_wifi(drw, x, y, sz=10, on=True):
    """Minimal Wi-Fi = dot + two arcs."""
    cx = x + sz // 2
    drw.ellipse((cx - 1, y + sz - 2, cx + 1, y + sz), fill=0)                      # dot
    drw.arc((x + 2, y + sz - 6, x + sz - 2, y + sz + 2), start=205, end=335, fill=0)
    drw.arc((x, y + sz - 10, x + sz, y + sz - 2), start=215, end=325, fill=0)
    if not on:
        _icon_slash(drw, x, y, sz)


def draw_icon_iphone(drw, x, y, sz=10, state="absent"):
    """iPhone presence, three states:
       'absent'    -> phone, slashed (not plugged / not seen by usbmux)
       'untrusted' -> phone + closed padlock (plugged, but Trust not granted or
                      the phone is locked, so lockdown info can't be read)
       'trusted'   -> phone + open padlock (Trust granted; the VPN config can be
                      decrypted)."""
    if state is True:
        state = "trusted"
    elif not state:
        state = "absent"
    px0, px1 = x + 2, x + sz - 2
    drw.rounded_rectangle((px0, y, px1, y + sz), radius=1, outline=0, width=1)
    drw.line((px0 + 1, y + 2, px1 - 1, y + 2), fill=0, width=1)                    # speaker
    cx = (px0 + px1) // 2
    if state == "absent":
        drw.ellipse((cx - 1, y + sz - 3, cx + 1, y + sz - 1), fill=0)              # home dot
        _icon_slash(drw, x, y, sz)
        return
    # Clear the screen so the glyph reads on white. untrusted -> a small closed
    # padlock (locked); trusted -> a checkmark (Trust granted, config decryptable).
    drw.rectangle((px0 + 1, y + 4, px1 - 1, y + sz - 1), fill=255)
    if state == "trusted":
        drw.line((px0 + 1, y + 6, px0 + 2, y + 8), fill=0, width=1)                # checkmark
        drw.line((px0 + 2, y + 8, px1 - 1, y + 5), fill=0, width=1)
    else:
        drw.arc((cx - 1, y + 4, cx + 1, y + 6), start=180, end=360, fill=0)        # closed shackle
        drw.rectangle((cx - 1, y + 6, cx + 1, y + 8), fill=0)                      # solid body (locked)


def _iphone_presence():
    """iPhone USB state for the status icon: 'absent' | 'untrusted' | 'trusted'.

    'trusted' = lockdown info is readable (SerialNumber), which is exactly what
    udid-mode decryption needs, so the VPN can come up. 'untrusted' = usbmux sees
    the device (a UDID) but lockdown is not accessible: Trust not granted, or the
    phone is locked. A running backup implies a present, trusted device, so skip
    the probe then to avoid piling lockdown queries onto idevicebackup2."""
    if _backup_running:
        return "trusted"
    if _wg_crypto is None:
        return "absent"
    try:
        if not _wg_crypto.get_iphone_udid():
            return "absent"
    except Exception:
        return "absent"
    try:
        return "trusted" if _wg_crypto.get_iphone_serial() else "untrusted"
    except Exception:
        return "untrusted"


def _compute_icon_status():
    """Sample VPN / internet / WiFi reachability and iPhone presence (blocking)."""
    vpn = internet = wifi = False
    try:
        iface = CFG.get("wireguard", {}).get("interface_name", "wg0")
        vpn = subprocess.run(["ip", "link", "show", iface],
                             capture_output=True, timeout=3).returncode == 0
    except Exception:
        pass
    if netutil is not None:
        try: wifi = netutil.get_wifi_ip() is not None
        except Exception: pass
        try: internet = bool(netutil.have_connectivity(timeout=2))
        except Exception: pass
    return {"vpn": vpn, "internet": internet, "wifi": wifi, "iphone": _iphone_presence()}


def get_icon_status():
    with _icon_status_lock:
        return dict(_icon_status)


def draw_status_bar(drw, LW, LH):
    """Bottom-left status row drawn LAST on every live screen: power (always on)
    then vpn / internet / wifi / iphone, each slashed when inactive. Reads the
    cached status only — no network I/O on the draw path.

    The icon area is cleared to white first, so even if a screen's text strayed
    into the bottom strip the icons can never end up overlapping it. Screens also
    reserve STATUS_BAR_H of bottom space, so normally nothing is here to clear."""
    st = get_icon_status()
    sz, gap = 10, 4
    n = 5
    icon_end = 3 + n * (sz + gap)
    drw.rectangle((0, LH - STATUS_BAR_H, icon_end, LH), fill=255)
    y = LH - sz - 2
    x = 3
    draw_small_power_icon(drw, x, y, size=sz);            x += sz + gap
    draw_icon_vpn(drw, x, y, sz, st["vpn"]);              x += sz + gap
    draw_icon_internet(drw, x, y, sz, st["internet"]);    x += sz + gap
    draw_icon_wifi(drw, x, y, sz, st["wifi"]);            x += sz + gap
    draw_icon_iphone(drw, x, y, sz, st["iphone"]);        x += sz + gap


def _normpath(p):
    if not p:
        return p
    return os.path.abspath(os.path.expanduser(os.path.expandvars(p)))


def get_ip_addr():
    try:
        out = subprocess.check_output(["hostname", "-I"], text=True, timeout=5).strip()
        return out.split()[0] if out else "No IP"
    except Exception:
        return "No IP"


def get_soc_temp():
    try:
        with open("/sys/class/thermal/thermal_zone0/temp", "r") as f:
            return round(int(f.read().strip()) / 1000, 1)
    except Exception:
        return None


def _device_to_mountpoint(dev):
    try:
        with open("/proc/mounts", "r") as f:
            rows = [ln.split() for ln in f.read().splitlines()]
        mp = None
        for src, mnt, *_ in rows:
            if src == dev and (not mp or len(mnt) > len(mp)):
                mp = mnt
        return mp
    except Exception:
        return None


def get_free_disk_pct():
    dev = CFG.get("disk_device")
    mp = _device_to_mountpoint(dev) if dev and str(dev).startswith("/dev/") else None
    if not mp:
        mp = _normpath(CFG.get("backup_dir")) or "/"
    try:
        st = os.statvfs(mp)
        total = st.f_blocks * st.f_frsize
        if total <= 0:
            return None
        return round(st.f_bavail * st.f_frsize / total * 100, 1)
    except Exception:
        return None


def _newest_backup_mtime():
    """Newest backup-folder mtime under backup_dir, or None. This is the last
    WRITE, not the last completed backup — an interrupted run bumps it too —
    which is why it is only the fallback below and the seed for the durable
    record, never the thing the staleness verdict trusts once one exists."""
    bd = _normpath(CFG.get("backup_dir"))
    if not bd or not os.path.isdir(bd):
        return None
    try:
        mtimes = [e.stat(follow_symlinks=True).st_mtime
                  for e in os.scandir(bd) if e.is_dir(follow_symlinks=True)]
        return max(mtimes) if mtimes else None
    except Exception:
        return None


def get_last_backup_str():
    """The info screen's "Backup:" line. Reads the durable record first: the
    folder scan reports the last write, so an interrupted run used to make this
    screen claim a backup that never finished. "(stale)" is only appended off the
    record — the mtime is not a completion signal, so calling it stale would be
    asserting something no evidence supports — and this is the exact screen
    someone taps when they wonder whether the thing is still working."""
    suffix = ""
    ts = _read_last_backup().get("completed_at")
    if isinstance(ts, (int, float)) and ts > 0:
        _, threshold = _stale_limits()
        if threshold and (time.time() - ts) >= threshold:
            suffix = " (stale)"
    else:
        ts = _newest_backup_mtime()
    if not ts:
        return "No backups"
    try:
        return time.strftime("%H:%M / %d %b %Y", time.localtime(ts)) + suffix
    except Exception:
        return "No backups"


def get_vpn_status():
    try:
        iface = CFG.get("wireguard", {}).get("interface_name", "wg0")
        r = subprocess.run(["ip", "link", "show", iface], capture_output=True, text=True, timeout=3)
        return "VPN: connected" if r.returncode == 0 else "VPN: off"
    except Exception:
        return "VPN: off"


def _wifi_nickname_for_ssid(ssid):
    """Nickname configured for ``ssid`` in config.yaml (read live), or ''."""
    if not ssid:
        return ""
    try:
        with open(CONFIG_PATH, "r") as f:
            live = yaml.safe_load(f) or {}
        for net in (live.get("wifi", {}).get("networks", []) or []):
            if (net.get("ssid") or "") == ssid:
                return (net.get("nickname") or "").strip()
    except Exception:
        pass
    return ""


def get_connection_line():
    """Active network for the info screen: WiFi (with nickname/SSID) vs iPhone
    hotspot vs Ethernet vs none.

    The type is decided from interface IPs (a single fast `ip addr` read), and the
    WiFi SSID is queried ONLY when actually on WiFi — so the info screen never
    spawns the wireless tools (iwgetid/iw/wpa_cli), which can each block for
    seconds while on the iPhone hotspot, stalling the button."""
    ip = typ = None
    if netutil is not None:
        try:
            ip, typ = netutil.get_active_ip()
        except Exception:
            ip = typ = None
    if typ == "wifi":
        ssid = None
        try:
            ssid = netutil.get_wifi_ssid()
        except Exception:
            ssid = None
        name = _wifi_nickname_for_ssid(ssid) or ssid
        return f"Net: WiFi {name}" if name else "Net: WiFi"
    if typ == "usb_iphone":
        return "Net: iPhone hotspot"
    if ip:
        return "Net: Ethernet"
    return "Net: none"


def _ts_full(iso):
    """Format an ISO timestamp exactly like the last-backup line ('%H:%M / %d %b
    %Y'), so the Sync line matches the Backup line on the info screen."""
    try:
        return datetime.fromisoformat(iso).strftime("%H:%M / %d %b %Y")
    except Exception:
        return ""


def get_last_sync_str():
    """Last/current remote-sync result for the info screen. The timestamp is
    formatted like get_last_backup_str() so both lines read consistently."""
    try:
        with open(STATUS_FILE, "r") as f:
            st = json.load(f)
        state = st.get("state")
        if state == "syncing":
            return "running"
        if state == "sync_complete":
            return ("OK " + _ts_full(st.get("timestamp"))).strip()
        if state == "sync_error":
            return ("failed " + _ts_full(st.get("timestamp"))).strip()
    except Exception:
        pass
    try:
        logs = glob.glob(os.path.join(LOG_DIR, "sync-*.log"))
        if logs:
            newest = max(logs, key=os.path.getmtime)
            return time.strftime("%H:%M / %d %b %Y", time.localtime(os.path.getmtime(newest)))
    except Exception:
        pass
    return "none"
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

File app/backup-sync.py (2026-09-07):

#!/usr/bin/env python3
# backup-sync.py — Double-tap / long-press / web UI: sync backups to remote server
#
# Does NOT touch the e-paper display. iosbackupmachine.py owns the EPD and reads
# this script's status writes from backup_status.json to render sync UI.
import os, sys, time, json, subprocess, yaml, traceback
from datetime import datetime

CONFIG_PATH = os.getenv("IOSBACKUP_CONFIG", "/root/iosbackupmachine/config.yaml")

# Make sibling modules importable when run via Popen from webui
SCRIPT_DIR = os.path.dirname(os.path.abspath(__file__))
if SCRIPT_DIR not in sys.path:
    sys.path.insert(0, SCRIPT_DIR)

import logutil
# Persistent logs on the rootfs; runtime status on the volatile zram /var/log.
LOG_DIR = logutil.LOG_DIR
RUNTIME_DIR = logutil.RUNTIME_DIR
STATUS_FILE = os.path.join(RUNTIME_DIR, "backup_status.json")


def load_config(path):
    try:
        with open(path, "r") as f:
            cfg = yaml.safe_load(f) or {}
    except Exception:
        cfg = {}
    cfg.setdefault("orientation", "landscape_right")
    cfg.setdefault("env", {})
    cfg.setdefault("sync", {"enabled": False})
    return cfg


def write_status(state, **extra):
    """Atomic status write: tmp file + rename, so concurrent readers never see partial JSON."""
    try:
        os.makedirs(RUNTIME_DIR, exist_ok=True)
        data = {"state": state, "timestamp": datetime.now().isoformat(), **extra}
        tmp = STATUS_FILE + f".tmp.{os.getpid()}"
        with open(tmp, "w") as f:
            json.dump(data, f)
            f.flush()
            try:
                os.fsync(f.fileno())
            except Exception:
                pass
        os.replace(tmp, STATUS_FILE)
    except Exception:
        try:
            if os.path.exists(tmp):
                os.remove(tmp)
        except Exception:
            pass


logf = None      # set by main() once the run log is open


def _probe_failed(name, exc):
    """A guard probe that cannot run must fail closed (assume busy): an
    overlapping rsync/backup is worse than a skipped sync. The failure goes to
    the journal (stderr) and, once open, the run log."""
    msg = f"[WARN] {name} probe failed ({exc}); assuming busy"
    print(msg, file=sys.stderr)
    if logf is not None:
        try:
            logf.write(msg + "\n")
        except Exception:
            pass


# Every probe below runs with timeout=5. Failing closed only helps if the probe
# returns at all: a pgrep or pkill wedged on an unresponsive /proc entry parks
# the run in the guard stage indefinitely, with no status, no exit and nothing
# in the log. A TimeoutExpired is exactly the "cannot run" case _probe_failed
# already handles.
def backup_running():
    try:
        out = subprocess.run(["pgrep", "-f", "idevicebackup2"],
                             capture_output=True, text=True, timeout=5)
        return out.returncode == 0
    except Exception as e:
        _probe_failed("backup_running", e)
        return True


def another_sync_running():
    """True if another backup-sync.py process is running."""
    try:
        out = subprocess.run(["pgrep", "-f", "backup-sync.py"],
                             capture_output=True, text=True, timeout=5)
        if out.returncode != 0:
            return False
        my_pid = os.getpid()
        my_ppid = os.getppid()
        for pid_str in out.stdout.split():
            try:
                pid = int(pid_str)
            except ValueError:
                continue
            if pid != my_pid and pid != my_ppid:
                return True
        return False
    except Exception as e:
        _probe_failed("another_sync_running", e)
        return True


def sync_in_progress():
    """True if a sync is already running — either another backup-sync.py or the
    in-process auto-sync in iosbackupmachine.py (status 'syncing' + a live rsync).
    Guards against kill_stale_rsync() killing an active auto-sync's rsync."""
    try:
        with open(STATUS_FILE, "r") as f:
            state = (json.load(f) or {}).get("state")
    except FileNotFoundError:
        return False       # no status yet: nothing has ever synced
    except Exception as e:
        _probe_failed("sync_in_progress status-file", e)
        return True        # unparseable status: assume a sync is active
    if state != "syncing":
        return False
    try:
        return subprocess.run(["pgrep", "-f", "/usr/bin/rsync"],
                              capture_output=True, timeout=5).returncode == 0
    except Exception as e:
        _probe_failed("sync_in_progress pgrep", e)
        return True


def kill_stale_rsync(logf):
    """Kill orphaned rsync processes left behind by previous interrupted runs."""
    try:
        r = subprocess.run(["pkill", "-9", "-f", "/usr/bin/rsync"],
                           capture_output=True, text=True, timeout=5)
        if r.returncode == 0:
            logf.write("[INFO] killed stale rsync processes\n")
    except Exception as e:
        logf.write(f"[WARN] kill_stale_rsync failed: {e}\n")
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

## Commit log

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2026-04-06 Move install dir to /root/iosbackupmachine, fix uninstall script
    - Change INSTALL_DIR from /root to /root/iosbackupmachine in both
    install.sh and uninstall.sh (app files co-locate with venv)
    - Update all service files, shell scripts, and Python defaults
    to use /root/iosbackupmachine/ paths
    - Add all missing files to uninstall.sh: boot-message.py,
    button-info.py, backup-sync.py, sync_crypto.py, sync_manager.py,
    button-info.service, backup-sync.service, encrypted config files
    - Uninstall also cleans up old /root/ install location
    [backup-sync.py, iosbackupmachine.py, notifications.py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]
2026-04-06 Fix 7 bugs: wizard pairing, display overflow, config overwrite, dashboard status
    1. Wizard now prompts user to connect iPhone first and runs
    idevicepair pair/validate before completing setup
    2. Unplug screen: split date to separate line, removed border
    to prevent text overflow on 250x122 display
    3. Font paths verified consistent across all scripts (all read
    from config.yaml font_path, fallback to PIL default)
    4. Renamed config.yaml to config.yaml.example and added
    config.yaml to .gitignore so git pull never overwrites
    user settings on the device
    5. Wizard skip on upgrade: config.yaml preserved (fix 4),
    so setup_completed flag persists across updates
    6. Set +x permissions on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
    [iosbackupmachine.py, webui.py]
2026-04-06 Fix first-backup: block before setup, add interactive pairing
    - iosbackupmachine.py: exit immediately if setup_completed is false,
    so plugging iPhone during wizard doesn't trigger a backup
    - webui.py: add /api/pair endpoint that runs idevicepair pair to
    trigger the "Trust this computer?" prompt on the iPhone
    - setup.html: replace static iPhone detection with interactive
    "Pair Device" button that calls /api/pair via AJAX and shows
    live pairing status (waiting/paired/denied)
    [iosbackupmachine.py, webui.py]
2026-04-06 v2.1: master password encryption, sync network filter, wizard fixes
    Breaking: credential encryption now uses a user-chosen master password
    instead of iPhone UDID. Existing encrypted configs must be re-encrypted.
    - Backup no longer starts before wizard is completed (setup_completed check)
    - Wizard restarts iosbackupmachine.service after completion so backup
    starts immediately without re-plugging the iPhone
    - Encryption check retries once to avoid false "not encrypted" warnings
    - Font path fallback to /root/iosbackupmachine/UbuntuMono-Regular.ttf
    in all 7 display scripts when config value is missing
    - Encryption password asked twice in wizard (confirmation field)
    - wg_crypto.py: derive_ke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
    [backup-sync.py, iosbackupmachine.py, sync_crypto.py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]
2026-04-06 Fix encryption status detection, clean up encryption page
    - Use ideviceinfo -k WillEncrypt (reliable) instead of broken
    idevicebackup2 -i flag to check encryption status
    - Fallback to idevicebackup2 encryption status if ideviceinfo fails
    - Remove confusing "Ever confirmed" field from encryption page
    - Simplify iPhone connection display
    [webui.py]
2026-04-06 Robust update process: backup, migrate, version track, web UI
    install.sh improvements:
    - Lock file prevents concurrent installs
    - Version tracking via .installed_version file
    - Skip prompt if already up to date
    - Pre-update backup of all files to timestamped dir (keeps 5)
    - Config migration: merges new defaults into existing config.yaml
    without overwriting user values (Python-based recursive merge)
    - Post-install health check: verifies critical files, Python deps,
    service status
    New files:
    - update.sh: one-command updater (git pull + install.sh), shows
    changelog since last install, checks if already up to date
    - webui_templates/system_update.html: web UI update page
    Web UI update pag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
    [webui.py]
2026-04-06 Add Case/ directory, update README with new layout and update docs
    - Add Case/Case ios backup machine_v8.stl (3D printable case)
    - Update directory layout in README to reflect v2.1 structure
    (new install path /root/iosbackupmachine/, all new files)
    - Add "Updating" section with web UI and SSH instructions
    - Fix config path reference to /root/iosbackupmachine/config.yaml
    [Case ios backup machine_v8.stl]
2026-04-06 Fix button press during backup: don't interrupt display or run sync
    - button-info.py: improved pgrep pattern (python.*iosbackupmachine\.py)
    to reliably detect running backup, exit without touching display
    - backup-sync.py: same pgrep fix, skip sync during active backup
    - iosbackupmachine.py: in-process button listener does nothing when
    _backup_running is true; also checks flag again after 10s sleep
    before resetting to "Waiting" (prevents race condition)
    [backup-sync.py, iosbackupmachine.py]
2026-04-06 Fix error display, disk space message, and unplug after error
    - error_and_exit renamed to error_and_wait: no longer calls sys.exit,
    instead waits for iPhone to be unplugged so the unplug-notify
    handler can show its screen properly
    - Long error messages truncated to 30 chars per line for e-ink display
    - Disk space errors (code 105/106) now show helpful message pointing
    to root filesystem (df -h) instead of generic idevicebackup2 text
    - unplug-notify.sh: removed guard that skipped when backup process
    not running — unplug screen now always shows when iPhone removed
    - Fixed pgrep pattern to python.*iosbackupmachine\.py for reliability
    [iosbackupmachine.py]
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2026-04-07 UDID/custom passphrase mode, single-tap during backup
    Credential encryption now supports two modes (configurable in web UI):
    - "udid": uses iPhone UDID as passphrase — WireGuard and sync
    auto-decrypt when iPhone is connected, no password prompt
    - "custom": user-chosen password — manual entry required each time
    wg_crypto.py: added resolve_passphrase() that reads passphrase_mode
    from config and auto-resolves UDID when in udid mode
    sync_crypto.py: delegates to wg_crypto.resolve_passphrase()
    wg_manager.py/sync_manager.py: use new passphrase resolution
    webui.py: WireGuard and sync routes respect passphrase_mode,
    conditionally show/hide password fields in templates
    config.yaml.example: ad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
    [iosbackupmachine.py, sync_crypto.py, sync_manager.py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]
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2026-04-07 Show detailed WireGuard start errors instead of generic failure
    wg_manager.start_wireguard now returns (success, error_message)
    with specific diagnostics: no iPhone, serial unreadable, wrong
    passphrase, wg-quick error output, missing tools, etc.
    [webui.py, wg_manager.py]
2026-04-07 Fix WireGuard/sync templates and encryption status detection
    - WireGuard template: passphrase mode selector, conditional password
    fields (only shown in custom mode, hidden in UDID/serial mode)
    - Sync template: same passphrase mode support, no password fields
    when using iPhone serial
    - Encryption page: fix detection using ideviceinfo backup domain
    (com.apple.mobile.backup WillEncrypt key), fallback to
    idevicebackup2 dry-run output parsing, last fallback to
    encryption_confirmed flag from config
    [webui.py]
2026-04-07 Show full wg-quick error: filter [#] lines, show last 5 error lines
    wg-quick echoes every command to stderr as [#] lines, hiding the
    actual error. Now filters those out and shows the last 5 real
    error lines, with 30s timeout instead of 15s.
    [wg_manager.py]
2026-04-07 Add WireGuard auto-connect when iPhone is plugged in
    - New auto_connect toggle in WireGuard settings page
    - iosbackupmachine.py: when iPhone triggers backup and auto_connect
    is enabled, starts WireGuard automatically using iPhone serial
    (only in udid passphrase mode, skips if already up)
    - webui.py: saves auto_connect setting to config
    [iosbackupmachine.py, webui.py]
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2026-04-07 Fix web UI update and version detection
    - update.sh/install.sh: fix version grep path (app/webui.py not
    webui.py) and use sed instead of grep -oP for portability
    - webui.py: fix remote version check path (origin/main:app/webui.py)
    - webui.py: run update.sh in background via Popen (the installer
    restarts the web UI, so subprocess.run never returns)
    - system_update.html: always enable Install Update button
    - Update log written to /var/log/iosbackupmachine/update.log
    [webui.py]
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2026-04-07 Add backup control buttons, fix auto-start on re-plug
    - Dashboard: Start Backup / Stop Backup buttons with API endpoints
    (/api/start-backup restarts service, /api/stop-backup kills it)
    - udev rule: changed 'start' to 'restart' so the backup service
    always re-runs when iPhone is plugged in (fixes auto-start)
    - WireGuard auto-reconnects on re-plug since iosbackupmachine.service
    restarts and re-runs the auto-connect check
    [iosbackupmachine.py, webui.py]
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2026-04-07 Fix false error detection: only trigger on known error codes
    The regex \berror\b matched any line containing "error" in
    idevicebackup2 output, causing false positives (e.g. during
    normal negotiation). Now only triggers error_and_wait when
    extract_error_code finds an actual known error code.
    Also updated error 208 message from "Wrong iPhone password"
    to "Unlock iPhone and try again" (more accurate).
    [iosbackupmachine.py]
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2026-04-07 Reliability, UX, and operations improvements
    Reliability:
    - Backup retry: auto-retries once on failure before showing error
    - Disk space pre-check: warns if root <500MB or backup drive <1GB
    free before starting backup
    - Backup integrity verification: checks Manifest.plist is valid
    after successful backup, reports in status and notifications
    User Experience:
    - Mobile hamburger menu for responsive sidebar navigation
    - Enhanced notifications: include device name, verified flag,
    backup size in webhook/MQTT payloads
    - Storage monitoring: dashboard shows backup drive and system disk
    usage with color-coded progress bars (green/amber/red)
    Operations:
    - Log rotation: logrotate config for we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
    [iosbackupmachine.py, webui.py]
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2026-04-07 Fix interrupted reason, add shutdown/reboot buttons, fix display timing
    1. Interrupted status now shows specific reason: 'Stopped from web
    UI' or 'iPhone unplugged' instead of hardcoded text
    2. Dashboard: Reboot and Shut Down buttons with confirmation dialogs
    3. owner-message.py: increased e-paper refresh wait from 2s to 5s
    to ensure display completes before power is cut
    4. shutdown.sh: shows owner info before calling shutdown -h now
    (belt and suspenders with the systemd ExecStop service)
    [webui.py]
2026-04-07 Long press starts backup, align animation squares with power icon
    Long press of UPS button triggers backup with safety checks:
    - Skips if install/update running (lock file check)
    - Skips if backup already running
    - Skips if no iPhone connected
    - Skips if setup not completed
    - Otherwise restarts iosbackupmachine.service
    Animation squares moved from LH-16 to LH-11 to vertically
    align with the power icon at LH-14.
    [iosbackupmachine.py]
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2026-04-07 Improve logging: prune progress bars, add log levels, live viewer
    Backup logs:
    - Progress bar lines ([====] 42% Finished) no longer written to log
    files (filtered in tee_and_parse). Logs only meaningful events.
    - Service stdout/stderr goes to systemd journal instead of
    autostart.log (eliminates duplication with per-session logs)
    Web UI logging:
    - Python logging module with RotatingFileHandler (2MB, 3 backups)
    - werkzeug request logging suppressed (too verbose)
    - Log levels: INFO for operations, WARNING/ERROR for issues
    Log viewer:
    - Auto-scrolls to bottom on page load
    - 'View Live Backup Log' button on logs page links to latest
    backup log with auto-refresh enabled
    - Empty log files h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
    [iosbackupmachine.py, webui.py]
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2026-05-27 Fix WireGuard not connecting on iPhone hot-plug
    The NM dispatcher only watched wlan* interfaces, so plugging
    the iPhone after boot never triggered wg-autoconnect for usb/eth.
    Also wait for connectivity before attempting wg-quick in the
    service restart path.
    [iosbackupmachine.py]
2026-05-27 Fix SSH key auth failing due to Windows line endings
    Strip carriage returns from pasted SSH keys at save time and
    when writing temp key files. OpenSSH's libcrypto rejects keys
    containing \r\n.
    [sync_manager.py, webui.py]
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2026-05-27 Add decrypt button for sync credentials, separate notification test buttons
    Sync page: Decrypt button reveals saved host/port/username/path when
    iPhone is connected. Leaving key/password empty on re-save preserves
    the existing value.
    Notifications page: separate Test Webhook, Test MQTT, and Test All
    buttons with individual success/failure feedback. Added sync_complete
    and sync_error to the event list.
    [webui.py]
2026-05-27 Fix rsync not found under systemd service PATH
    Use absolute path /usr/bin/rsync for local invocation and
    --rsync-path for the remote side, since systemd and restricted
    SSH shells may not include /usr/bin in PATH.
    [sync_manager.py]
2026-05-27 Fix sync never running: backup guard matched the always-running main service
    backup_running() checked for python.*iosbackupmachine.py which is the
    main service loop, not an active backup. Changed to check for
    idevicebackup2 (the actual backup process) in both backup-sync.py
    and long-press-backup.sh.
    Also replaced silently disabled Sync Now / Test Connection buttons
    with toast messages explaining why they can't be used.
    [backup-sync.py]
2026-05-27 Run web UI sync in background thread to avoid blocking the page
    Sync Now was blocking Flask's request thread for the entire rsync
    duration, making the page appear stuck. Now runs in a background
    thread, returns immediately with a flash message, and updates the
    dashboard status file with progress.
    [webui.py]
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2026-05-29 Fix silent sync failures, add dashboard Sync Now button, live sync log
    backup-sync.py was initializing the e-paper display before writing
    the syncing status or opening its log file. After a power loss event
    (UPS battery die) the SPI bus is left in a state where epd.init() can
    hang or throw, killing the script before any visible output. From the
    outside it looked like nothing was happening — dashboard stayed
    "Idle", e-ink stayed blank, no log file appeared.
    Restructure backup-sync.py:
    - Open sync-TIMESTAMP.log first so every step is traceable.
    - Write "syncing" status BEFORE EPD init so dashboard reflects state
    even if the display fails.
    - Wrap EPD init in try/except; show_message() beco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
    [backup-sync.py, sync_manager.py, webui.py]
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2026-05-29 Detect stalled rsync; persist sync result on e-ink until next event
    When rsync stops producing output (silent connection drop, remote
    hang, etc.) the previous code would wait up to 1 hour with no
    feedback. Now sync_manager watches stdout with select(2): after 30s
    of no data it surfaces a "Stalled" state to the dashboard and e-ink
    display; after 10 minutes it kills the process and reports failure.
    SSH gains ServerAliveInterval=30 / ServerAliveCountMax=3 so dead
    TCP connections are detected in ~90s instead of waiting for the
    kernel keepalive (~2h).
    The sync_complete / sync_error screen now persists on the e-ink
    forever — replaced only by a new sync, a backup, a device-rejected
    event, or a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
    [backup-sync.py, iosbackupmachine.py, sync_manager.py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]
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2026-05-29 Don't flag rsync file-list scan as a stall
    With --no-inc-recursive, rsync walks the whole source tree before
    producing any progress output. On large iPhone backups (200k+ files)
    this scan takes several minutes — long enough to trigger the 30s
    stall warning the previous version emitted at sync start.
    Split the watchdog into two phases:
    - Scan phase (no progress line yet): after 5s, surface a
    "Building file list (Xs)" status to dashboard and e-ink so the
    user knows it's working; kill only after 30 min of total silence.
    - Transfer phase (at least one progress line received): real stall
    detection — warn at 30s, kill at 10 min.
    Dashboard shows a blue "Scanning" badge with el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
    [backup-sync.py, iosbackupmachine.py, sync_manager.py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]
2026-05-29 Cancel Sync button; longer stall thresholds; auto-scaled bytes
    - Stall thresholds bumped for slow ARM SBC + slow remotes:
    warn at 2 min (was 30s), kill at 15 min (was 10 min).
    - New POST /sync/cancel endpoint kills rsync + backup-sync.py and
    writes "Cancelled by user." status. Cancel Sync button appears
    on the dashboard and Remote Sync settings page only while a sync
    is running; the dashboard polls toggle its visibility live.
    - Dashboard sync card now renders byte counts with auto-scaled units
    (B / KB / MB / GB / TB) via a new human_size Jinja filter on the
    server and matching JS helper for live updates — no more
    unreadable "5174.4 MB / 129359.9 MB".
    Bump to 3.8.
    [sync_manager.py, webui.py]
2026-05-29 Harden e-ink sync display: atomic writes, button no-op, crash detection
    Several races and overrides could prevent rsync progress from
    showing on the e-ink. Address them at the source:
    - Atomic status writes (tmp + os.replace) in both backup-sync.py
    and iosbackupmachine.py. Concurrent readers can no longer see a
    partially-written JSON file and silently fall back to "no state".
    - PiSugar single-tap (IP info overlay) now checks the status file
    first and skips entirely when state=syncing. Previously it would
    save ui.state, draw IP info for 10s, then restore the SAVED state
    — losing every sync progress update that arrived during that
    window.
    - Main loop now sets ui.state every iter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
    [backup-sync.py, iosbackupmachine.py, webui.py]
2026-05-29 Style disabled buttons; clean leftovers on sync (re)start
    Two bugs reported by the user:
    1. The "Sync Now" button looked identical whether enabled or
    disabled — the CSS had no :disabled rule. Add one (grey
    background, muted text, not-allowed cursor, hover override).
    2. After Cancel Sync, clicking Sync Now sometimes left the e-ink
    stuck on the previous result and produced no progress. Cause:
    /sync/cancel used pkill (SIGTERM) on backup-sync.py. The python
    process can linger in the proc table just long enough that the
    newly-launched backup-sync.py's own another_sync_running() guard
    sees it and exits silently — no status write, no display update.
    Fix:
    - /sync/can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
    [webui.py]
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2026-05-30 Phase 1: reliability + config architecture (README To-do)
    Implements the six unit-testable items from the README To-do; the single
    e-paper-owner display refactor is deferred to its own follow-up (needs
    on-device validation).
    Architecture
    - config_schema.py: single source of defaults, versioned schema + migration
    step, and atomic config writes (tmp + fsync + rename) so a power loss
    mid-save can no longer truncate config.yaml. webui.py, iosbackupmachine.py
    and install.sh now go through it; the old setdefault chains and in-place
    yaml.dump writes are gone.
    Reliability
    - /api/health (login-exempt, no secrets): service states, disk, battery,
    network, last backup/sync, with an ok/warnin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
    [backup-sync.py, config_schema.py, iosbackupmachine.py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]
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2026-05-30 Fix on-device issues from Phase 2 testing
    - Reboot flag: add a per-release REBOOT_EPOCH file. install.sh compares it to
    an installed .reboot_epoch marker and requires a reboot when it advances,
    instead of hardcoding "no reboot required". Bump the integer in any commit
    that needs a reboot. This update sets epoch 1 (prompts a reboot once).
    - Single-tap when iPhone plugged + auto-backup disabled: the main loop's
    per-iteration ui.set was clobbering the system-info screen. Passive screens
    (idle/boot, auto-backup-disabled, rejected, sync result) now go through a
    show() guard that yields while the 30s info window is active; backup/sync
    still override it.
    - PiSugar tap mapping: doubl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
    [iosbackupmachine.py]
2026-05-30 Fix backup-complete screen ghosting into the sync progress screen
    E-paper partial refresh could leave the just-finished "Backup completed"
    message ghosting behind the sync progress screen. Add a one-shot full-refresh
    request (Animator.request_full) that the next rendered frame honours, and fire
    it on screen-type transitions: device-detected, backup-complete -> sync,
    sync -> result, and the status-file transitions into syncing / sync_complete /
    sync_error (manual sync). A forced full refresh clears the previous screen so
    it cannot bleed through the partial updates that follow.
    [iosbackupmachine.py]
2026-05-30 Sync logging: separate auto-sync log + throttle progress spam
    Two inconsistencies in sync logging:
    1. Auto-sync (after a backup) wrote its [SYNC] lines and rsync output into the
    *backup* log, while a manual sync logs to its own sync-*.log. Auto-sync now
    opens its own sync-*.log too; the backup log just gets a one-line pointer.
    2. Progress was logged once per second ("[SYNC] 0% (183s)" ...), bloating the
    log during slow/scanning/stalled transfers. Now:
    - the on_progress callbacks (auto-sync + backup-sync.py) log only on a
    percent change or every 30s — a stuck sync leaves a sparse trail you can
    still read, and scan/stall transitions are still logged once each;
    - sy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
    [backup-sync.py, iosbackupmachine.py, sync_manager.py]
2026-05-30 Display/sync fixes from on-device testing (overlap, overflow, stalls)
    Issue 1 — text overflow: Panel now word-wraps subtitles and center-block
    messages to the 250px display width, so long messages (e.g. the stall abort)
    no longer run off the edge. The stall/scan abort messages are also shortened.
    Issue 2 — backup must not run without an iPhone, and never alongside a sync:
    - Web UI "Start Backup" refuses when no iPhone is connected.
    - The start sentinel window is cut from 60s to 15s, so a request can't silently
    fire a backup minutes later when an iPhone is finally plugged in.
    - Mutual exclusion: the daemon never starts a backup while a sync is running
    (pgrep backup-sync.py); backup-s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
    [iosbackupmachine.py, sync_manager.py, webui.py]
2026-05-30 Robust backup/sync mutual exclusion + fix result-screen overlap
    Overlap after a failed sync: the auto-full-refresh I added keyed screen
    transitions on bool(center_block), so two different "complete" screens (e.g.
    "Sync failed" -> another result) shared a key and didn't full-refresh — the old
    text ghosted. The layout key is now content-aware for static screens (subtitle /
    center_block / info_lines), so any change in a static screen forces one clean
    full refresh. Animated progress still uses partial refresh (content excluded),
    so backup/sync % stays smooth.
    Backup and sync are now mutually exclusive across every trigger:
    - backup-sync.py refuses if a backup runs (idevicebackup2) OR a sync i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
    [backup-sync.py, iosbackupmachine.py, webui.py]
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
